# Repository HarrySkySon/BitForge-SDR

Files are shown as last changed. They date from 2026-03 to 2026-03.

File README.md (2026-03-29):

<p align="center">
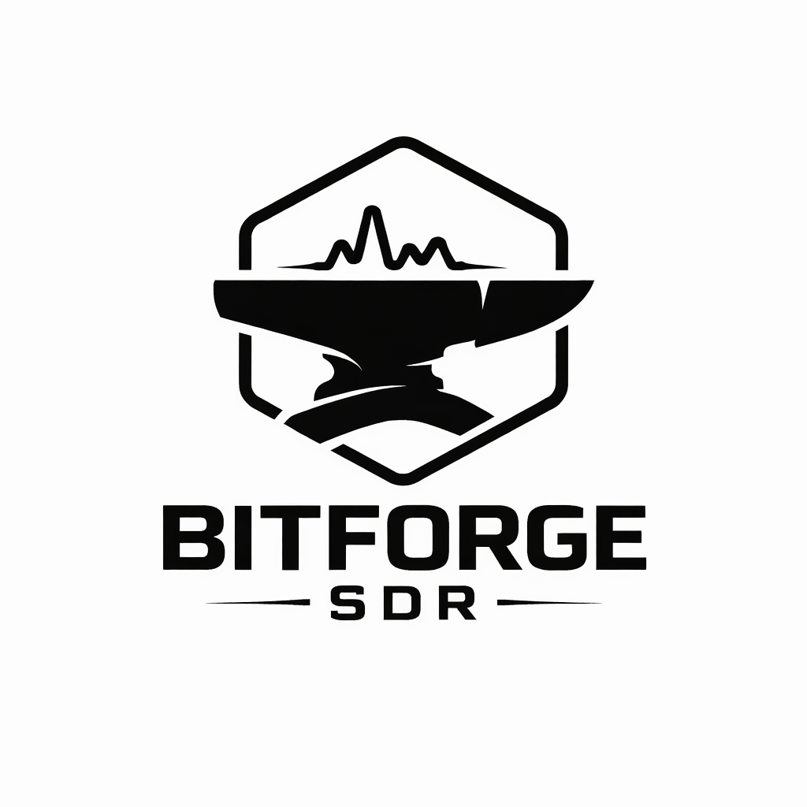
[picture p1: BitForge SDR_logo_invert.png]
BitForge SDR Logo
  
</p>

<h1 align="center">BitForge SDR</h1>

<p align="center">
  <b>Pure Signal. Full Control.</b><br>
  Open-Source 16-bit Direct-Sampling HF SDR Transceiver | 9 kHz -- 72 MHz | >100 dB Dynamic Range
</p>

A high-performance Software Defined Radio transceiver built around the LTC2209 16-bit 153.6 MSPS ADC and MAX5885 16-bit DAC. Designed for demanding HF reception from VLF through the 4-meter band, with full transmit capability and instrumentation-grade dynamic range.

> **Note:** This project is under active development. The hardware design (schematics + PCB) is complete. FPGA firmware is in progress.

---

## Key Specifications

| Parameter | Value |
|---|---|
| **ADC** | LTC2209 -- 16-bit, 153.6 MSPS |
| **DAC** | MAX5885 -- 16-bit, 200 MSPS (clocked at 153.6 MSPS) |
| **Frequency range** | 9 kHz -- 72 MHz (VLF through 4m band) |
| **Nyquist bandwidth** | 76.8 MHz |
| **Dynamic range** | >100 dB (dual DSA cascade) |
| **SFDR** | 100 dB (typical) |
| **Noise figure** | 3.0 dB (LTC6432 dominated) |
| **Output IP3** | +33 dBm (at ADC driver output) |
| **Clock jitter** | <50 fs RMS (Si5391B, integer mode) |
| **Gain range** | -63.5 dB to +15.2 dB (0.25 dB steps) |
| **Filter bands** | 7 switched BPF + wideband master LPF |
| **ADC interface** | LVDS differential (17 pairs, DDR @ 153.6 MHz) |
| **RX/TX switching** | Atomic, single-pin, <100 ns |
| **FPGA platform** | ALINX AXU2CGB (Xilinx Zynq UltraScale+) |

---

## Why This Project?

### 16-bit at 153.6 MSPS -- wider Nyquist than LTC2208 designs

Most open-source direct-sampling SDRs use the LTC2208 (130 MSPS). The LTC2209 pushes the sample rate to 153.6 MSPS, extending the Nyquist bandwidth to 76.8 MHz and comfortably covering the entire 9 kHz -- 72 MHz range without aliasing concerns at the band edges.

### Dual Digital Step Attenuators with 0.25 dB resolution

Two PE43711A DSAs in cascade provide 63.5 dB of digitally controlled attenuation in 0.25 dB steps. This is finer than most SDR designs (which use 0.5 dB or 1 dB steps) and enables precise AGC control from the FPGA without sacrificing signal quality.

### LTC6432 combined LNA/ADC driver -- a unique topology

Instead of the traditional separate-LNA-plus-ADC-driver chain (PGA-103 + ADA4937 or similar), this design uses the LTC6432-15 as a combined low-noise amplifier and differential ADC driver. The result is a simpler signal path with +15.2 dB fixed gain, 3.0 dB noise figure, and +33 dBm OIP3 -- all in a single IC with dual-balun impedance matching.

### 7-band switched filter bank + wideband master LPF

Two PE42582A SP8T switches route the signal through one of seven optimized bandpass filters (90 kHz -- 73 MHz) or a wideband master LPF covering the full 9 kHz -- 72 MHz range. The master LPF provides a panoramic view of the entire HF spectrum for digital waterfall display, while the BPFs deliver sharp selectivity when zoomed into a specific band.

### Si5391B integer-mode clock -- zero fractional spurs

The clock synthesizer operates in pure integer mode: 38.4 MHz TCXO x4 = 153.6 MHz. No fractional dividers means zero fractional spurs on the SDR waterfall -- a real advantage over designs using fractional-N PLLs with 25 MHz references. Clock jitter is below 50 fs RMS, preserving the full 16-bit ADC performance.

### Full transmit path with 16-bit DAC

The MAX5885 16-bit DAC shares the same signal chain (filter bank, LTC6432, and RF switches) in reverse for TX. Atomic RX/TX switching is controlled by a single FPGA pin with <100 ns transition time -- no sequencing logic required.

### Extended range: 9 kHz -- 72 MHz

Coverage extends from VLF (9 kHz) through the entire HF spectrum and up to the 4-meter band (70 MHz). The 3-stage RF choke network in the LNA power supply is specifically designed for continuous performance from 9 kHz to 72 MHz without resonant dips.

---

## Comparison with Existing SDR Platforms

| Parameter | **BitForge SDR** | Hermes-Lite 2 | HPSDR Angelia | RX-888 MKII | Red Pitaya SDRlab 122-16 | Elad FDM-S3 |
|---|---|---|---|---|---|---|
| **ADC resolution** | 16-bit | 12-bit | 16-bit | 16-bit | 16-bit | 16-bit |
| **Sample rate** | 153.6 MSPS | 76.8 MSPS | 122.88 MSPS | 64 MSPS | 122.88 MSPS | 192 MSPS |
| **SFDR** | 100 dB | ~70 dB | 100 dB | 78 dB | 90 dB | 100 dB |
| **Dynamic range** | >100 dB | ~80 dB | >100 dB | ~85 dB | ~90 dB | >100 dB |
| **Frequency range** | 9 kHz -- 72 MHz | 0 -- 38.4 MHz | 0 -- 61.44 MHz | 0 -- 32 MHz | 0 -- 60 MHz | 9 kHz -- 108 MHz |
| **TX capability** | Yes (16-bit DAC) | Yes (12-bit) | Yes | No | Yes (14-bit) | No |
| **Filter bands** | 7 BPF + master LPF | 5 LPF | 7 BPF | None | None | 6 BPF |
| **Clock jitter** | <50 fs | Not specified | Not specified | Not specified | Not specified | Not specified |
| **Gain control step** | 0.25 dB | 1 dB | 0.5 dB | 0.5 dB | Analog | 0.5 dB |
| **ADC driver** | LTC6432 (LNA+driver) | ADC direct | ADA4937 | LTC6401 | ADC direct | Proprietary |
| **License** | CERN-OHL-S v2 | GPL | GPL | Closed | Closed | Closed |
| **Approx. price** | ~$150 (PCB+BOM) | ~$300 | ~$800+ | ~$200 | ~$500 | ~$1,200 |

---

## Architecture

```
                            ┌─────────────────────────────────┐
                            │        FPGA (Zynq US+)          │
                            │   ALINX AXU2CGB via J701/J901  │
                            │                                 │
                            │  J701: ADC LVDS (17 diff pairs) │
                            │  J901: DAC data + control (3.3V)│
                            └──┬──────────────┬───────────────┘
                               │              │
                          ADC LVDS        DAC data + /RX_TX_MODE
                               │              │
┌─────────┐   ┌─────────┐   ┌─┴──────┐   ┌───┴──────┐
│ SMA RX  │   │Block 1  │   │Block 7 │   │ Block 9  │
│  Input  ├──►│DSA1     │   │LTC2209 │   │ MAX5885  │
│  (J101) │   │0-31.75dB│   │ADC     │   │ DAC      │
└─────────┘   └────┬────┘   └───▲────┘   └────┬─────┘
                   │             │              │
              ┌────▼─────────────┴──────────────┴────┐
              │          Block 4: RF Switches         │
              │       3x F2912 (atomic RX/TX)         │
              │  RX: Antenna→ADC  TX: DAC→Antenna     │
              └────────────────┬──────────────────────┘
                               │
                   ┌───────────▼───────────┐
                   │  Block 6: LTC6432     │
                   │  LNA/ADC Driver       │
                   │  +15.2 dB, NF=3.0 dB  │
                   │  Dual balun topology   │
                   └───────────▲───────────┘
                               │
                   ┌───────────┴───────────┐
                   │  Block 5: DSA2        │
                   │  0 -- 31.75 dB        │
                   │  0.25 dB steps        │
                   └───────────▲───────────┘
                               │
              ┌────────────────┴────────────────┐
              │  Blocks 2-3: Switched Filter Bank│
              │  7x BPF + Master LPF (0-72 MHz) │
              │  2x PE42582A SP8T switches       │
              └─────────────────────────────────┘

              ┌─────────────────────────────────┐
              │  Block 8: Clock Generation       │
              │  Si5391B (<50 fs jitter)         │
              │  38.4 MHz TCXO x4 = 153.6 MHz   │
              │  Integer mode, zero spurs        │
              └─────────────────────────────────┘
```

**Signal flow (RX):** Antenna → ESD protection → Balun → DSA1 → Filter Bank → DSA2 → LTC6432 → RF switches → LTC2209 ADC → LVDS → FPGA

**Signal flow (TX):** FPGA → MAX5885 DAC → RF switches → Filter Bank → DSA2 → LTC6432 → RF switches → Antenna

---

## Repository Contents

| Path | Description |
|---|---|
| `README.md` | This file |
| `LICENSE` | CERN Open Hardware Licence v2 -- Strongly Reciprocal |
| `BitForge SDR_logo_invert.png` | Project logo |
| `PROJECT_OVERVIEW_v2.0.md` | Detailed technical overview of all 9 functional blocks |
| `ALINX_Interface_Pinout_Specification.md` | FPGA carrier board connector pinout mapping |
| `FPGA_Interface_Voltage_Analysis.md` | Voltage level and bank compatibility analysis |
| `pcb_design/PCB_STACKUP_IMPEDANCE.md` | PCB stackup and controlled impedance specifications |
| `schematics/All_Bloks_of_project.kicad_sch` | Top-level KiCad schematic (all blocks) |
| `schematics/All_Bloks_of_project.kicad_pcb` | PCB layout |
| `schematics/All_Bloks_of_project.kicad_pro` | KiCad project file |
| `schematics/All_Bloks_of_project.kicad_dru` | Design rules |
| `schematics/production/LTC2209_SDR.zip` | Production Gerber files |
| `schematics/production/LTC2209_SDR_bom.csv` | Bill of Materials |
| `schematics/bom/ibom.html` | Interactive BOM (open in browser) |

---

## Getting Started

### Prerequisites

- **KiCad 8.0** or later -- [https://www.kicad.org/download/](https://www.kicad.org/download/)
- A web browser (for the interactive BOM)

### Viewing the Design

1. **Schematics:** Open `schematics/All_Bloks_of_project.kicad_pro` in KiCad. The top-level schematic contains all 9 functional blocks with hierarchical sheets.

2. **PCB Layout:** Open the same project file and switch to the PCB editor, or open `schematics/All_Bloks_of_project.kicad_pcb` directly.

3. **Interactive BOM:** Open `schematics/bom/ibom.html` in any web browser. This provides a visual, searchable component placement overlay on the PCB -- no KiCad installation required.

4. **Production files:** The `schematics/production/` directory contains ready-to-order Gerber files and BOM.

### FPGA Platform

This board connects to the **ALINX AXU2CGB** carrier board (Xilinx Zynq UltraScale+ XCZU2CG) via two 2x20 pin headers:
- **J701** (mapped to ALINX J12): ADC LVDS interface -- 16 data pairs + 1 clock pair
- **J901** (mapped to ALINX J15): DAC data bus + control signals (3.3V LVCMOS)

See `ALINX_Interface_Pinout_Specification.md` for the complete pin mapping.

---

## License

This project is licensed under the **CERN Open Hardware Licence Version 2 -- Strongly Reciprocal** ([CERN-OHL-S v2](https://ohwr.org/cern_ohl_s_v2.txt)).

See the [LICENSE](LICENSE) file for the full text.

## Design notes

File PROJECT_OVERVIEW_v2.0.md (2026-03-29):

# SDR Receiver/Transceiver Project - Technical Overview

**Version:** 2.9
**Date:** 2026-01-25
**Status:** RX/TX Complete (LVDS interface, 3.3V control, optimized Block 6)

---

## PROJECT SUMMARY

**Name:** Software Defined Radio (SDR) Receiver with LTC2209 ADC
**ADC:** LTC2209 (16-bit, 160 MSPS)
**DAC:** MAX5885 (16-bit, 200 MSPS)
**Frequency Range:** 9 kHz - 72 MHz
**Dynamic Range:** >100 dB (with dual DSA)
**Gain:** 15.2 dB (fixed, LTC6432 LNA/Driver)

---

## BLOCK STRUCTURE

The project consists of **9 functional blocks** with continuous component numbering:

| Block | Prefix | Function | Key ICs | Purpose |
| --- | --- | --- | --- | --- |
| **Block 1** | 100s | Input Stage | PE43711A-Z, TC1-1T | Input protection, balancing, DSA1 |
| **Block 2, 3** | 200s | Switched Filter Bank | 2x PE42582A-X | Multi-band filtering (7 bands) + Master LPF 0 - 72 MHz |
| **Block 4** | 400s | RX/TX RF Switching | 3x F2912NCGI8 | RF switching between RX and TX modes |
| **Block 5** | 500s | Second DSA | PE43711A-Z | Additional digital attenuation |
| **Block 6** | 600s | LNA/ADC Driver | LTC6432AIUF-15 | LNA + differential driver (+15.2dB) for RX/TX |
| **Block 7** | 700s | ADC + Interface | LTC2209, TPS7A9101 | 16-bit ADC + FPGA interface (RX) |
| **Block 8** | 800s | Clock Generation | Si5391B-A-GM | Ultra-low jitter clock (38.4 MHz TCXO -> 153.6 MHz) |
| **Block 9** | 900s | DAC & TX Interface | MAX5885, LP5912 | 16-bit DAC + FPGA interface (TX) |

---

## DETAILED BLOCK DESCRIPTIONS

### **BLOCK 1: Input Stage & DSA1** (100s prefix)

#### **Key Components:**

- **IC101** - LP5907MFX-3.3: Ultra-low noise LDO (3.3V, 250mA)
- **IC104** - PE43711A-Z: 6-bit Digital Step Attenuator (0-31.75 dB, 0.25dB steps)
- **T101** - TC1-1T: 1:1 RF Transformer (50 ohm impedance matching)
- **TVS101** - CDSOD323-T05LC: Transient Voltage Suppressor
- **J101** - SMA RX: Input coaxial connector

#### **Functions:**

1. **ESD/Overvoltage Protection** (TVS101)
2. **Single-ended to Differential Conversion** (T101)
3. **Digital Control Gain** (IC104): 0 to -31.75 dB, FPGA controlled
4. **Clean Power Supply** (IC101) for DSA

#### **Control:**

- **DSA_SCLK, DSA_DATA, DSA_LE1**: SPI control for DSA1 (7-bit attenuation values)

#### **Specifications:**

- **Input impedance:** 50 ohm
- **IP3:** +42 dBm (PE43711A)
- **Insertion Loss:** ~3 dB @ 0 dB attenuation

---

### **BLOCK 2: Switched Filter Bank** (200s prefix)

#### **Key Components:**

- **IC201** - PE42582A-X: SP8T RF Switch (input)
- **IC202** - LP5907MFX-3.3: LDO for switch power supply
- **IC203** - PE42582A-X: SP8T RF Switch (output)
- **L301-L356, C301-C374**: 7x LC Band-Pass Filters
- **Master LPF:** Wideband filter covering the full dynamic range 9 kHz - 72 MHz. Designed to provide a complete passband overview with subsequent digital processing and filtering in the FPGA

#### **Architecture:**

```
IC201 (SP8T) -> [7x Bandpass Filters and Master LPF 9 kHz - 72 MHz] -> IC203 (SP8T)
     |                                        |
  FLT_V1-V4                               FLT_V1-V4
  (4-bit binary)                          (4-bit binary)
```

#### **Filters (7 bands):**

| Band | Filter Path | Frequency Range | Components |
| ---- | --- | --- | --- |
| 1 | RF_FILTR_IN/OUT_1 | 0.09 - 1.6 MHz  | L301-L305, C301-C305 |
| 2 | RF_FILTR_IN/OUT_2 | 1.5 - 4 MHz | L306-L312, C306-C315 |
| 3 | RF_FILTR_IN/OUT_3 | 4 - 8 MHz | L313-L319, C316-C327 |
| 4 | RF_FILTR_IN/OUT_4 | 8 - 15.5 MHz | L320-L327, C328-C341 |
| 5 | RF_FILTR_IN/OUT_5 | 15 - 30 MHz | L328-L333, C342-C351 |
| 6 | RF_FILTR_IN/OUT_6 | 30 - 50 MHz | L334-L337, C352-C358 |
| 7 | RF_FILTR_IN/OUT_7 | 47 - 73 MHz | L338-L347, C359-C374 |
| 8 | MASTER_LPF_IN/OUT | 0.09 - 72 MHz | L338-L347, C359-C374 |

#### **Master LPF:**

- **MASTER_LPF_IN** -> L348-L356 -> **MASTER_LPF_OUT**
- Wideband filter covering the full dynamic range 9 kHz - 72 MHz.

#### **Control:**

- **FLT_V1, FLT_V2, FLT_V3, FLT_V4**: 4-bit binary control for both switches (synchronous switching)
  Band selection is performed programmatically. The user initially sees the full 9 kHz - 72 MHz band. This allows them to view the radio spectrum and choose software tools and filters for signal processing. When the user zooms into a specific range, the corresponding BPF filter is selected, providing fine signal filtering in that band.

#### **Functions:**

####

#### **Specifications:**

- **Isolation:** >55 dB (PE42582A)
- **Insertion Loss:** ~0.5 dB per switch
- **Switching Speed:** <500 ns

---

### **BLOCK 4: RX/TX RF Switching** (400s prefix)

#### **Key Components:**

- **IC401, IC402, IC403** - F2912NCGI8: SP2T RF switches (Renesas)
- **IC404, IC405** - LP5907MFX-3.3: LDO for switch power supply

#### **Functions:**

- **IC401:** TX signal injection from DAC into shared RX/TX signal path (Filter Bank)
- **IC402/IC403:** Routing of LTC6432 differential outputs between ADC (RX) and TX antenna
- **1-pin control:** All switches + ADC/DAC are controlled by a single `/RX_TX_MODE` signal

#### **Architecture:**

```
        RX Mode (/RX_TX_MODE = LOW):
Antenna -> Filter Bank -> LTC6432 -> IC402/IC403 (RF1) -> ADC (active)
                      (DAC shutdown)

        TX Mode (/RX_TX_MODE = HIGH):
DAC (active) -> IC401 (RF2) -> Filter Bank -> LTC6432 -> IC402/IC403 (RF2) -> TX Antenna
                                                    (ADC shutdown)
```

#### **Atomic RX/TX Control (single signal):**

**Switch Control Truth Table:**

| Mode | /RX_TX_MODE | F2912 (IC401-403) | LTC2209 SHDN | MAX5885 PD |
| --- | --- | --- | --- | --- |
| **RX** | LOW (0V) | RF1 ON (RX path)  | LOW (active) | HIGH (off) |
| **TX** | HIGH (3.3V) | RF2 ON (TX path)  | HIGH (off) | LOW (active) |

**Control Signal Path:**

```
FPGA (J15, BANK25/26, 3.3V) -> J901.32 -> RX_TX_MODE
                                          +-- IC401.16 (CTL2) -> F2912 #1
                                          +-- IC402.16 (CTL2) -> F2912 #2
                                          +-- IC403.16 (CTL2) -> F2912 #3
                                          +-- IC701.19 (SHDN) -> LTC2209
```

**Control Current Budget (FPGA 3.3V LVCMOS output):**

| Component | Pins | Current per pin | Total |
| --- | --- | --- | --- |
| F2912 CTL2 (x3) | IC401-403.16  | 500 nA max | **1.5 uA**  |
| LTC2209 SHDN | IC701.19 | ~1 uA | **1 uA** |
| U902 input | Level shifter | ~1 uA | **1 uA** |
| **Total** | | | **~3.5 uA** |

**FPGA IOH/IOL capability: 8-12 mA -> margin >2000x**

#### **F2912 Configuration (3.3V Control Mode):**

- **Pin 18 (LOGICCTL)** = **GND** -> **3.3V logic mode enabled**
- **Pin 19 (ModeCTL)** = VCC -> 1-pin control mode
- **Pin 16 (CTL2)** = RX_TX_MODE -> Control input (3.3V logic)
- **Logic thresholds (3.3V):** VIH min = 2.0V, VIL max = 0.8V

**Advantage of LOGICCTL=GND:**

- Direct control via 3.3V signal from FPGA J15 (BANK25/26)
- Does not require level shifter IC704 (removed)
- Simplified circuit, fewer components

#### **Specifications:**

- **Switching time:** <100 ns (RF switches)
- **Isolation:** >74 dB (RF1/RF2 @ 1 GHz)
- **Insertion Loss:** <0.5 dB @ HF frequencies
- **Control:** Single FPGA pin `/RX_TX_MODE` (LVCMOS33, J901.32)

---

### **BLOCK 5: Second DSA** (500s prefix)

#### **Key Components:**

- **IC501** - LP5907MFX-3.3: LDO for DSA2
- **IC502** - PE43711A-Z: 6-bit Digital Step Attenuator

#### **Functions:**

- **Digital attenuation:** Additional digital attenuation (0 to -31.75 dB). Step size 0.25 dB
- **Dual DSA cascade** with Block 1 for wide dynamic range (0 to -63.5 dB total)

#### **Control:**

- **DSA_SCLK, DSA_DATA, DSA_LE2**: SPI control for DSA2 (7-bit attenuation values)

#### **Specifications:**

- Identical to IC104 (Block 1)
- **Total Gain Range:** 0 to -63 dB (with Block 1)

---

### **BLOCK 6: LNA/ADC Driver** (600s prefix) - **NEW DESIGN**

#### **Key Components:**

- **IC601** - **LTC6432AIUF-15#PBF**: Differential LNA/Driver (+15.2 dB gain)
- **IC602** - TPS7A9401DSCR: Ultra-low noise LDO
- **T601** - TTWB-2-A: 1:2 Input Balun (single-ended to differential), Bandwidth = 50 kHz to 200 MHz
- **T602** - CX2041NLT: 1:1 Output Balun (re-balancing + common-mode biasing), Bandwidth = 50 kHz to 200 MHz
- **L601, L611, L602, L603, L612, L604**: Power supply chokes + output filter inductors
- **C601-C622**: Coupling, bypass, and filter capacitors
- **R601-R608**: Input termination, biasing, output termination

#### **Architecture:**

```
RF_1 -> T601 (1:2 balun) -> IC601 (LTC6432) -> T602 (2:1 balun) -> ADC
       50 ohm single-ended     Diff. Amp         Output balancing   Differential
                           Gain = +15.2dB                           to LTC2209
                                  |
                            IC602 (5V LDO)
```

#### **Pinout LTC6432 (IC601):**

| Pin | Function | Connection |
| --- | --- | --- |
| 5 | NFILT2 | C605 (1uF) filter cap |
| 6 | NFILT1 | C606 (1uF) filter cap |
| 7 | -In | From T601 via C602 |
| 8, 15, 17, 23, 25 | GND | Ground plane |
| 9, 22 | +VS | +5V (from IC602) |
| 12 | -FDBK | C608 (1uF) feedback |
| 13 | -OUT | To T602 via C614 |
| 18 | +OUT | To T602 via C613 |
| 19 | +FDBK | C607 (1uF) feedback |
| 24 | +In | From T601 via C601 |
| 1-4, 10-11, 14-16, 20-21 | DNC | Do Not Connect |

#### **Input Network:**

```
RF_1 (from Block 5) -> T601 (TTWB-2-A, 1:2) -> +/-In (IC601)
                      50 ohm SE -> 200 ohm diff      Pins 24, 7
```

#### **Output Network:**

```
IC601 +/-OUT -> C613/C614 (1uF) --+-- R622/R623 (2.2k ohm shunt)
                               +-- T602 (CX2041NLT, 1:1) -> ADC differential input
                                   Center tap -> LTC2209 VCM
```

#### **Power Supply: 3-Stage RF Choke Network**

Three-stage RF choke network for continuous coverage of the 9 kHz - 72 MHz range:

```
+5V_B6 -+- L601 (470uH) -+- L611 (47uH) -+- L602 (560nH) -+- IC601 +VS
        |                |               |                |
        +- R603 (390 ohm) -+- R620 (82 ohm) -+- R604 (54 ohm) ---+
```

| Stage | Inductor | De-Qing R | Effective Range |
| ----- | --- | --- | --- |
| LF | L601 (470uH) | R603 (390 ohm) | 9 kHz - 1 MHz |
| MF | L611 (47uH)  | R620 (82 ohm)  | 500 kHz - 6 MHz |
| HF | L602 (560nH) | R604 (54 ohm)  | 5 MHz - 72 MHz  |

**Specifications:**

- Total DCR: 1.86 ohm -> DC drop: 130 mV -> VCC = 4.87V (within specification)
- Z_choke @ 72 MHz: 516 ohm
- Worst resonance: Q=72 @ 213 kHz (well damped)

#### **LTC6432 Specifications:**

- **Gain:** +15.2 dB (fixed)
- **Noise Figure:** 3.0 dB @ 100 MHz
- **Output IP3:** +33 dBm
- **Bandwidth:** 100 kHz to 1400 MHz (-3dB)
- **Output Impedance:** 50 ohm differential
- **Supply Current:** 165 mA @ 5V
- **DC Power:** 850mW

#### **Block Functions:**

1. **Low Noise Amplification:** +15.2 dB with NF = 3.0 dB
2. **Single-ended to Differential Conversion** (T601)
3. **Differential Output Balancing** (T602)
4. **ADC Common-Mode Biasing** (T602 center tap -> VCM)
5. **Output Filtering** (L605/L606 + C617/C618/C619)
6. **Clean Power Supply** (IC602 ultra-low noise LDO)

#### **Key Features:**

- **Dual Balun Architecture:** T601 (TTWB-2-A, 1:2) + T602 (CX2041NLT, 1:1), BW = 50 kHz - 200 MHz
- **3-Stage RF Choke:** Continuous coverage 9 kHz - 72 MHz without resonant dips
- **Optimized De-Qing:** R603=390 ohm, R620=82 ohm, R604=54 ohm for Q-factor control
- **Shunt Resistors:** R622/R623 (2.2k ohm) for additional LC resonance damping
- **T602 VCM Biasing:** Center tap connected to LTC2209 VCM for ADC DC biasing

---

### **BLOCK 7: ADC & FPGA Interface** (700s prefix)

#### **Key Components:**

- **IC701** - LTC2209IUPPBF: 16-bit ADC (153.6 MSPS)
- **IC702** - TPS7A9101DSKT: Precision LDO for analog supply (3.3V)
- **IC703** - LP5907MFX-1.8: LDO for digital outputs (1.8V)
- **J701** - Pin Header 2x20: FPGA interface connector (LVDS data)
- **J901** - Pin Header 2x20: Control signals + ADC_OF (3.3V)
- **C701** - 10uF: VCM bypass capacitor
- **C702, C711, C712** - Decoupling capacitors for VDD (3.3V)
- **C703, C718** - Decoupling capacitors for OVDD (1.8V)

#### **ADC Specifications:**

- **Resolution:** 16 bits
- **Sample Rate:** 153.6 MSPS (from Block 8)
- **Nyquist Bandwidth:** 76.8 MHz (covers 9 kHz - 72 MHz range)
- **Noise Floor:** 77.3 dBFS
- **SFDR:** 100 dB (typical)
- **Output Format:** 2's Complement (16-bit parallel)
- **Output Mode:** **LVDS Differential** (17 pairs via J701)
- **Power Dissipation:** ~1.0W @ 153.6 MSPS

#### **Output Mode: LVDS Differential**

**Why LVDS:**

- **High speed:** DDR at 153.6 MHz = 307.2 Mbps per lane
- **Noise immunity:** Differential signals with common-mode rejection
- **Compatibility:** FPGA HP banks (BANK65/66) have native LVDS support
- **Termination:** Built-in 100 ohm resistors in FPGA (DIFF_TERM_ADV TERM_100)

**LTC2209 LVDS Output Structure:**

- **DA0-DA15:** 8 differential pairs (Bus A)
- **DB0-DB15:** 8 differential pairs (Bus B)
- **CLKOUTA/CLKOUTB:** 1 differential pair (Data Clock Output)
- **OFA/OF-:** Overflow -> J901 pins 21/22 (single-ended 3.3V)
- **Total LVDS pairs on J701:** 17 (all J12 pairs utilized)

**LVDS Electrical Characteristics:**

| Parameter | Value |
| --- | --- |
| Common Mode (VOS) | 1.125V - 1.2V - 1.375V |
| Differential (VOD) | 247mV - 350mV - 454mV |
| FPGA Input Common Mode | 0.3V - 1.5V (compatible) |
| FPGA Min Differential  | >100mV (350mV >> 100mV OK) |
| Termination | 100 ohm internal in FPGA |

#### **Control Pins Configuration:**

| Pin | Name  | Connected  | Function | Reasoning |
| --- | ----- | --- | --- | --- |
| 1 | SENSE | VDD (3.3V) | Internal 2.5V reference | Uses internal bandgap reference |
| 19  | SHDN  | RX_TX_MODE | Shutdown control | 3.3V from FPGA via J901.32 |
| 20  | DITH  | GND | Dither disabled | Better SNR for SDR (~3dB improvement) |
| 61  | LVDS  | VDD (3.3V) | LVDS mode enabled | Differential output via J701 |
| 62  | MODE  | VDD (3.3V) | 2's Complement format | Standard for DSP/SDR processing |
| 63  | RAND  | GND | Normal output | No XOR randomization needed |
| 64  | PGA | GND | Gain=1, 2.25Vpp range | LTC6432 provides sufficient gain |

#### **Dual Supply Architecture:**

- **VDD (3.3V):** Analog core supply (pins 5,6,15,16,17)
  - Source: IC702 (TPS7A9101) ultra-low noise LDO
  - Decoupling: C702 (1uF), C711 (47uF), C712 (10nF)

- **OVDD (1.8V):** Digital output drivers (pins 32,49)
  - Source: IC703 (LP5907-1.8) ultra-low noise LDO
  - Decoupling: C703 (1uF), C718 (2.2uF)
  - Powers LVDS output drivers

- **VCM (Pin 3):** Output voltage reference (0.95V typical)
  - Bypass: C701 (10uF, >=2.2uF per datasheet)
  - Connected to T602 center tap for DC bias

#### **Analog Inputs:**

- **IN+ (Pin 8), IN- (Pin 9):** Differential analog inputs
  - Connected to ADC_P_OUT, ADC_N_OUT (from Block 6 via T602)
  - Input range: 2.25Vp-p differential (PGA=0)
  - Series termination: R607/R608 (25 ohm each)

#### **Clock Input:**

- **ENC+ (Pin 12), ENC- (Pin 13):** Differential clock inputs
  - Connected to CLK_0, CLK_B (from Block 8)
  - Clock frequency: 153.6 MHz (from Si5391B OUT0/OUT0b)
  - AC coupled via C809, C818 (100nF)
  - Terminated: R701 (100 ohm differential)

#### **Digital Outputs (LVDS to FPGA via J701):**

- **DA0-DA15, DB0-DB15:** 16 differential pairs (32 lines)
  - Output standard: LVDS (VOS=1.2V, VOD=350mV)
  - Data format: 2's Complement (MODE pin = VDD)
  - DDR transfer: both edges of CLKOUT
  - Connected to J701 pins 3-36 -> FPGA J12 (BANK65/66)

- **CLKOUTA/CLKOUTB (Pins 41, 40):** Data clock output
  - LVDS differential pair
  - Connected to J701 pins 15/16 -> FPGA IO1_7 (GC-capable)
  - Frequency: 153.6 MHz (same as ENC clock)

- **OFA/OF- (Pins 60, 59):** Overflow indicator
  - Connected to J901 pins 21/22 -> FPGA BANK25/26 (3.3V)
  - Used as single-ended signals on HR banks

---

### **BLOCK 8: Clock Generation** (800s prefix)

#### **Key Components:**

- **IC801** - Si5391B-A-GM: Ultra-low jitter clock generator (QFN-65, 12 outputs)
- **X801** - 38.4 MHz TCXO: Temperature-compensated crystal oscillator
- **C801-C817** - Decoupling capacitors: Power supply filtering
- **R801, R802** - 2.2k ohm: I2C pull-up resistors

#### **Architecture:**

```
X801 (38.4 MHz TCXO) -> IC801 (Si5391B PLL) -> OUT0/OUT0b (153.6 MHz) -> LTC2209 CLK+/-
                         ^
                    I2C_SCL, I2C_SDA
                    (FPGA configuration)
```

#### **Clock Generation:**

```
38.4 MHz TCXO (X801)
    | XA/XB (pins 8/9)
Si5391B DSPLL (IC801)
    +- VCO: ~5 GHz (internal)
    +- Integer Mode (clean spectrum, no fractional spurs)
    +- MultiSynth dividers
         |
OUT0/OUT0b (pins 24/23) -> 153.6 MHz differential -> LTC2209 CLK+/- (IC701.12/13)
```

#### **I2C Interface:**

- **I2C_SEL (pin 39)** = +1.8V -> I2C mode
- **SCLK (pin 16)** -> FPGA I2C_SCL (with 2.2k ohm pull-up)
- **SDA (pin 18)** -> FPGA I2C_SDA (with 2.2k ohm pull-up)
- **A1/A0 (pins 17/19)** = GND -> I2C address **0x68**

#### **Input Selection:**

- **IN_SEL0/IN_SEL1 (pins 3/4)** = GND -> explicit XA/XB selection (crystal input)
- **XA/XB (pins 8/9)** -> connected to 38.4 MHz TCXO (X801)

#### **Si5391B Specifications for Project Requirements:**

- **Jitter:** <50 fs RMS (Integer Mode, Precision Calibration)
- **Output frequency:** 153.6 MHz (4/1 ratio - Integer Mode) (programmable via I2C)
- **Sample rate:** 153.6 MSPS
- **Nyquist bandwidth:** 76.8 MHz
- **Coverage:** 9 kHz - 72 MHz with margin
- **Reference:** 38.4 MHz TCXO
- **Mode:** Integer (38.4 MHz x 4/1 = 153.6 MHz) -> no fractional spurs
- **Usable bandwidth:** 0-68 MHz (with margin up to 72 MHz)
- **Filter transition band:** 68-76.8 MHz (~12% margin)
- **Data throughput:** 153.6 MSPS x 16 bit = 2.46 Gbit/s
- **Output format:** Differential LVDS/LVPECL (configurable)
- **Power:** 1.8V (VDD core) + 3.3V (VDDA analog)

#### **Clock Performance:**

**Jitter budget (for LTC2209 16-bit ADC):**

```
ADC SNR = -20 x log10(2*pi * f_sample * t_jitter)

@ 153.6 MSPS, 153.6 MHz clock:
  Si5391B: <50 fs RMS
  -> Jitter-limited SNR: ~94 dBFS
  -> ENOB: ~15.3 bits (theoretical)
  -> LTC2209 spec: 77.3 dBFS noise floor (16-bit ENOB achievable!)
```

#### **Integer Mode Advantage:**

**Fractional-N vs Integer Mode:**

- **Fractional:** 25 MHz x 6.144 = 153.6 MHz -> produces spectral spurs (birdies on SDR waterfall)
- **Integer:** 38.4 MHz x 4 = 153.6 MHz -> clean spectrum, ideal for SDR

**Integer Mode calculation:**

```
38.4 MHz x 4 = 153.6 MHz
-> Simple integer multiplier (4x)
-> No fractional dividers needed
-> Zero fractional spurs
```

#### **Block Functions:**

1. **Ultra-low jitter clock generation** (<50 fs RMS)
2. **Integer Mode operation** (clean spectrum without fractional spurs)
3. **Dual LDO power supply** (analog/digital power isolation)
4. **I2C programmability** (ClockBuilder Pro configuration)
5. **Input filtering** (ferrite beads + decoupling caps)
6. **Temperature-stable reference** (38.4 MHz TCXO)

#### **Control:**

- **I2C_SCL, I2C_SDA:** Si5391B programming (address 0x68)
- **Configuration:** Via ClockBuilder Pro software (Silicon Labs)
- **Startup:** Configuration loaded via I2C after power-on
  I2C_SCL / I2C_SDA are REQUIRED in the current design because:
  1. Standard Si5391B-A-GM is used - no custom NVM
  2. At each power-up the FPGA must load the configuration:
  - Input: 38.4 MHz TCXO on XA/XB
  - Output: 153.6 MHz LVDS on OUT0/OUT0b
  - Mode: Integer (no fractional spurs)
  - PLL settings: 38.4 x 4 = 153.6 MHz
  3. Without I2C programming, the Si5391B will operate with factory default settings
  Alternative (for future revisions):
  Order a factory pre-programmed Si5391B through ClockBuilder Pro:
  - Silicon Labs will assign a unique part number (Si5391B-Axxxxx-GM)
  - The IC will automatically start with the correct configuration
  - I2C can then be removed or kept only for monitoring

#### **FPGA Interface:**

**Connection via I2C:**

```
FPGA (J12) -> J701 -> Si5391B
  Pin 34 (IO1_16P, C8) -> I2C_SCL -> IC801.16 (with 2.2k ohm pull-up)
  Pin 35 (IO1_17N, A8) -> I2C_SDA -> IC801.18 (with 2.2k ohm pull-up)
```

**Configuration:**

- **I2C Address:** 0x68 (7-bit, A1=GND, A0=GND)
- **Clock speed:** 400 kHz (Fast Mode)
- **Config size:** ~300 bytes (ClockBuilder Pro generated)
- **Init time:** ~25-40 ms (once at boot)

**Initialization Sequence:**

1. Power-on -> POR (~10 ms)
2. FPGA I2C write (~5-10 ms) -> config registers
3. PLL lock (~10-20 ms)
4. Clock ready (153.6 MHz)

#### **Power Architecture (CRITICAL FEATURE!):**

**Always-on power supply (independent of RX/TX mode):**

```
+3.3V (always on) -> Si5391B
```

**Why always on:**

- TX path (MAX5885 DAC) also requires a clock
- RX and TX share a single clock source
- Configuration loaded once at boot (no re-init required after mode switching)
- PLL always locked -> stable clock

**Power Consumption:**

- **Si5391B:** ~165 mA @ 1.8V/3.3V -> **~357 mW** (always on)
- **For comparison:** LTC6432 = 850 mW, TX PA = 5-10W
- **Conclusion:** Negligible power consumption, but critical advantage in switching speed!

---

### **BLOCK 9: DAC & TX Interface** (900s prefix)

#### **Key Components:**

- **IC901** - MAX5885EGM+D: 16-bit DAC (153.6 MSPS, TX path)
- **U901** - TPS7A9401DSCR: Ultra-low noise LDO (3.3V, 0.46 uVRMS)
- **U902** - SN74LV1T04DCKR: Inverter for PD control
- **T902** - RF Transformer (center-tapped balun)
- **R903, R904** - 25 ohm: DC return path resistors
- **R901** - 2k ohm: Full-scale current set resistor
- **C915/C916, C917/C918** - Parallel decoupling (1uF || 100nF)

#### **DAC Specifications:**

- **Resolution:** 16 bits, 200 MSPS
- **Update Rate:** 153.6 MSPS (from Block 8, OUT3/OUT3b)
- **Nyquist Bandwidth:** 76.8 MHz (covers 9 kHz - 72 MHz)
- **Output Mode:** Differential current outputs (IOUTP, IOUTN)
- **Full-Scale Current:** 19.2 mA (with R901 = 2k ohm)
- **Output Format:** 2's Complement (16-bit parallel)

#### **Output Stage:**

```
IC901 Pin 19 (IOUTP) --+-- R904 (25 ohm) -> GND  (DC path)
                       +-- C917 (1uF)  |
                       +-- C918 (100nF)-+--> T902 Pin 3

IC901 Pin 18 (IOUTN) --+-- R903 (25 ohm) -> GND  (DC path)
                       +-- C915 (1uF)  |
                       +-- C916 (100nF)-+--> T902 Pin 1

T902 Center Tap --> C919 (100nF) --> GND
T902 Output --> RF Switches (shared RX/TX signal path)
```

**Parallel Decoupling:** 1uF || 100nF provides low impedance across the full 9 kHz - 72 MHz range

#### **TX Architecture:**

The TX signal uses the **shared signal path** with RX through:

- Block 2-3: Filter Bank (PE42582A switches)
- Block 5: DSA (bypass in TX mode)
- Block 6: LTC6432 amplifier
- RF switches control signal direction (RX/TX)

---

## SIGNAL FLOW

```
+-------------+
|   SMA RX    | RF Input (1-30 MHz)
|   (J101)    |
+------+------+
       | 50 ohm single-ended
+------v--------------------------------------------------------+
| BLOCK 1: Input Stage                                          |
|  TVS101 -> T101 (1:1) -> IC104 (DSA1: 0 to -31.75dB)        |
|                              ^ DSA_SCLK, DSA_DATA, DSA_LE1   |
|                              ^ +5V (always on)                |
+------+--------------------------------------------------------+
       | Differential
+------v--------------------------------------------------------+
| BLOCK 2: Switched Filter Bank                                 |
|  IC201 (SP8T) -> [7x BPF] -> IC203 (SP8T) -> Master LPF     |
|       ^ FLT_V1-V4            ^ FLT_V1-V4                     |
|       ^ +5V (always on)                                       |
+------+--------------------------------------------------------+
       | Filtered differential
+------v--------------------------------------------------------+
| BLOCK 5: Second DSA                                           |
|  IC502 (DSA2: 0 to -31.75dB)                                 |
|         ^ DSA_SCLK, DSA_DATA, DSA_LE2                        |
|         ^ +5V (always on)                                     |
+------+--------------------------------------------------------+
       | Attenuated differential
       | RF_1 (single-ended equivalent)
+------v--------------------------------------------------------+
| BLOCK 6: LNA/ADC Driver                                      |
|  T601 (1:2) -> IC601 (LTC6432, +15.2dB) -> T602 (1:1)       |
|               |                              |                |
|               IC602 (5V LDO)                VCM -> ADC        |
|               ^ +5V (always on)                               |
+------+----------------------------------------+---------------+
       | ADC_P_OUT, ADC_N_OUT (differential)     | ADC_VCM
       | 2Vp-p @ 200 ohm impedance               |
+------v-----------------------------------------v--------------+
| BLOCK 7: ADC & Interface                                      |
|  IC701 (LTC2209: 16-bit, 153.6 MSPS)                         |
|    +- ADC_CLK_IN <- Block 8 (153.6 MHz)                      |
|    +- ADC_D[15:0] + DCO -> FPGA (J701)                       |
|  IC702, IC703: Power supplies                                 |
|    ^ +5V (always on)                                          |
+------+-------------------+------------------------------------+
       |                   | ADC_CLK_IN
       |         +---------v------------------------------------------+
       |         | BLOCK 8: Clock Generation                          |
       |         |  X801 (38.4 MHz TCXO)                              |
       |         |    |                                               |
       |         |  IC801 (Si5391B: <50fs jitter)                     |
       |         |    | Integer Mode (no spurs)                       |
       |         |  OUT0/OUT0b -> 153.6 MHz diff.                     |
       |         |  U801/U802: Dual LDO (1.8V + 3.3V)                |
       |         |    ^ +5V (always on)                               |
       |         |    ^ I2C_SCL, I2C_SDA (FPGA config)                |
       |         +----------------------------------------------------+
       |
   +---v---------+                 +----------------------------------+
   |   FPGA      | <-/RX_TX_MODE--| BLOCK 4: RX/TX RF Switching      |
   |   (J701)    |   (atomic)     |  3x F2912NCGI8 (SP2T switches)   |
   +-------------+                |  + ADC SHDN + DAC PD control      |
                                  |  Current: ~3.5uA from FPGA pin    |
                                  +----------------------------------+
```

---

## POWER DISTRIBUTION

### **Supply Rails:**

| Rail | Voltage | Source | Load | Current |
| --- | --- | --- | --- | --- |
| **+5V** | 5.0V | External | All blocks (always on) | ~1.2A |
| **+5V_OUT2** | 5.0V | IC602 (Block 6) | IC601 (LTC6432) | 50mA |
| **+3.3V_CLK** | 3.3V | U802 (Block 8) | IC801 VDDA (analog PLL) | ~80mA |
| **+1.8V_CLK** | 1.8V | U801 (Block 8) | IC801 VDD + VDDO (digital)  | ~85mA |
| **+3.3V_DIGITAL** | 3.3V | IC702 (Block 7) | IC701 digital I/O | ~50mA |
| **+3.3V_ANALOG**  | 3.3V | LDOs (Blocks 1,2,4,5) | DSA + RF Switches | ~180mA  |
| **+1.8V_ADC** | 1.8V | IC703 (Block 7) | IC701 digital core | ~40mA |

### **Power Management:**

- **All blocks are always on** - no power switching

**ADC/DAC Control (single /RX_TX_MODE signal from FPGA):**

- **RX_TX_MODE** (3.3V LVCMOS via J901.32):
  - Direct connection to IC701.19 (LTC2209 SHDN)
  - Direct connection to F2912 switches (IC401-403.CTL2)
  - RX Mode: LOW -> SHDN=LOW (ADC active)
  - TX Mode: HIGH -> SHDN=HIGH (ADC shutdown)

- **U902** (SN74LV1T04): Inverter for DAC PD control
  - Input: /RX_TX_MODE (J901.32)
  - Output: IC901.10 (MAX5885 PD, inverted)
  - RX Mode: LOW -> PD=HIGH (DAC powered down)
  - TX Mode: HIGH -> PD=LOW (DAC active)

### **Power Architecture:**

- **All blocks are always on** - simplified architecture without power switching
- **Advantage:** Instant RX/TX switching via RF switches (<100 ns)
- **ADC/DAC control:** Shutdown via SHDN/PD pins instead of power supply switching
- **Power consumption:** ~1.2A @ 5V constant (TX and RX modes are identical)

---

## FPGA CONTROL INTERFACE

### **Control Signal Architecture:**

**DSA Control (SPI):**

- **Shared SPI bus** for DSA1 and DSA2 (IC104, IC502)
- **DSA_SCLK, DSA_DATA:** shared bus (clock + data)
- **DSA_LE1, DSA_LE2:** separate Latch Enable (chip select) for each DSA
- **Pins required:** 4 (saving 2 pins compared to separate SPI buses)

**Filter Control (Binary):**

- **4-bit binary control** for PE42582A-X switches (IC201, IC203)
- **FLT_V1-V4:** parallel control of both switches (synchronous switching)
- **Channels:** 16 possible (8 used: 7 BPF + Master LPF)

**System Control (atomic single-signal control):**

- **/RX_TX_MODE:** single control signal for RX/TX switching (J901.32, LVCMOS33)
  - LOW (0V) = RX mode (ADC active, DAC shutdown, RF1 path)
  - HIGH (3.3V) = TX mode (DAC active, ADC shutdown, RF2 path)
  - Controls: F2912 switches (IC401-403.CTL2) + LTC2209 SHDN (direct) + MAX5885 PD (U902)
  - Load current: ~3.5 uA (margin >2000x from FPGA IOH/IOL)

### **J701 Connector Pinout (LTC2209 LVDS Interface):**

J701 is now used **exclusively for the LVDS interface** with the LTC2209 ADC.

| Pin | Signal | Direction  | Description |
| ----- | --- | --- | --- |
| 1 | GND | -- | Ground |
| 2 | +5V | Power | Main power supply |
| 3-4 | DB0/DB1 | ADC -> FPGA | LVDS Data Bus B pair 0 |
| 5-6 | DB2/DB3 | ADC -> FPGA | LVDS Data Bus B pair 1 |
| 7-8 | DB4/DB5 | ADC -> FPGA | LVDS Data Bus B pair 2 |
| 9-10  | DB6/DB7 | ADC -> FPGA | LVDS Data Bus B pair 3 |
| 11-12 | DB8/DB9 | ADC -> FPGA | LVDS Data Bus B pair 4 |
| 13-14 | DB10/DB11 | ADC -> FPGA | LVDS Data Bus B pair 5 |
| 15-16 | CLKOUT+/- | ADC -> FPGA | **DCO (GC-capable IO1_7)** |
| 17-18 | DB12/DB13 | ADC -> FPGA | LVDS Data Bus B pair 6 |
| 19-20 | DB14/DB15 | ADC -> FPGA | LVDS Data Bus B pair 7 |
| 21-22 | DA0/DA1 | ADC -> FPGA | LVDS Data Bus A pair 0 |
| 23-24 | DA2/DA3 | ADC -> FPGA | LVDS Data Bus A pair 1 |
| 25-26 | DA4/DA5 | ADC -> FPGA | LVDS Data Bus A pair 2 |
| 27-28 | DA6/DA7 | ADC -> FPGA | LVDS Data Bus A pair 3 |
| 29-30 | DA8/DA9 | ADC -> FPGA | LVDS Data Bus A pair 4 |
| 31-32 | DA10/DA11 | ADC -> FPGA | LVDS Data Bus A pair 5 |
| 33-34 | DA12/DA13 | ADC -> FPGA | LVDS Data Bus A pair 6 |
| 35-36 | DA14/DA15 | ADC -> FPGA | LVDS Data Bus A pair 7 |
| 37-38 | GND | -- | Ground |
| 39-40 | +3.3V | Power | 3.3V supply |

**Note:** All 17 differential pairs on J701/J12 are used for LVDS. DCO is assigned to GC-capable pair IO1_7 (pins 15-16).

### **J901 Connector Pinout (DAC Data + Control Signals, 3.3V):**

J901 connects to ALINX J15 -> FPGA BANK25/26 (HR banks, VCCO = 3.3V LVCMOS).
Used for **DAC TX data, control signals, and ADC overflow**.

| Pin | Signal | J15 FPGA Pin | Direction | Description |
| --- | --- | --- | --- | --- |
| 1 | GND | -- | -- | Ground |
| 2 | +5V | VCC5V | Power | 5V supply from ALINX |
| 3 | -- | IO2_1N (A11) | -- | Not connected |
| 4 | TX_SEL0 | IO2_1P (A12) | FPGA -> DAC | MAX5885 mode select (IC901.30) |
| 5 | TX_D15 | IO2_2N (A13) | FPGA -> DAC | DAC data bit 15 (IC901.33) |
| 6 | TX_D14 | IO2_2P (B13) | FPGA -> DAC | DAC data bit 14 (IC901.34) |
| 7 | TX_D13 | IO2_3N (A14) | FPGA -> DAC | DAC data bit 13 (IC901.35) |
| 8 | TX_D12 | IO2_3P (B14) | FPGA -> DAC | DAC data bit 12 (IC901.36) |
| 9 | TX_D11 | IO2_4N (E13) | FPGA -> DAC | DAC data bit 11 (IC901.37) |
| 10  | TX_D10 | IO2_4P (E14) | FPGA -> DAC | DAC data bit 10 (IC901.38) |
| 11  | TX_D9 | IO2_5N (A15) | FPGA -> DAC | DAC data bit 9 (IC901.39) |
| 12  | TX_D8 | IO2_5P (B15) | FPGA -> DAC | DAC data bit 8 (IC901.40) |
| 13  | TX_D7 | IO2_6N (C13) | FPGA -> DAC | DAC data bit 7 (IC901.41) |
| 14  | TX_D6 | IO2_6P (C14) | FPGA -> DAC | DAC data bit 6 (IC901.44) |
| 15  | TX_D5 | IO2_7N (B10) | FPGA -> DAC | DAC data bit 5 (IC901.45) |
| 16  | TX_D4 | IO2_7P (C11) | FPGA -> DAC | DAC data bit 4 (IC901.46) |
| 17  | TX_D3 | IO2_8N (D14) | FPGA -> DAC | DAC data bit 3 (IC901.47) |
| 18  | TX_D2 | IO2_8P (D15) | FPGA -> DAC | DAC data bit 2 (IC901.48) |
| 19  | TX_D1 | IO2_9N (F11) | FPGA -> DAC | DAC data bit 1 (IC901.1) |
| 20  | TX_D0 | IO2_9P (F12) | FPGA -> DAC | DAC data bit 0 (IC901.2) |
| 21  | TX_XOR | IO2_10N (H13)| FPGA -> DAC | MAX5885 XOR input (IC901.3) |
| 22  | -- | IO2_10P (H14)| -- | Not connected |
| 23  | ADC_OF_N | IO2_11N (G14)| ADC -> FPGA | LTC2209 Overflow- (IC701.59), 47 ohm series |
| 24  | ADC_OF_P | IO2_11P (G15)| ADC -> FPGA | LTC2209 Overflow+ (IC701.60), 47 ohm series |
| 25  | DSA_LE2 | IO2_12N (F10)| FPGA -> DSA2 | PE43711 #2 Latch Enable (via R912, 47 ohm) |
| 26  | DSA_LE1 | IO2_12P (G11)| FPGA -> DSA1 | PE43711 #1 Latch Enable (via R913, 47 ohm) |
| 27  | DSA_SCLK | IO2_13N (H12)| FPGA -> DSA | DSA SPI Clock (via R910, 47 ohm) |
| 28  | DSA_DATA | IO2_13P (J12)| FPGA -> DSA | DSA SPI Data (via R911, 47 ohm) |
| 29  | FLT_V2 | IO2_14N (J14)| FPGA -> Filters| Filter select bit 1 (via R918, 47 ohm) |
| 30  | FLT_V1 | IO2_14P (K14)| FPGA -> Filters| Filter select bit 0 (via R914, 47 ohm) |
| 31  | FLT_V4 | IO2_15N (K12)| FPGA -> Filters| Filter select bit 3 (via R917, 47 ohm) |
| 32  | FLT_V3 | IO2_15P (K13)| FPGA -> Filters| Filter select bit 2 (via R915, 47 ohm) |
| 33  | I2C_SDA | IO2_16N (L13)| FPGA <-> Si5391B| I2C Data (4.7k ohm pull-up, no series R) |
| 34  | RX_TX_MODE | IO2_16P (L14)| FPGA -> System | **Atomic RX/TX** (F2912+LTC2209+DAC, via R916 47 ohm)|
| 35  | -- | IO2_17N (G10)| -- | Not connected |
| 36  | I2C_SCL | IO2_17P (H11)| FPGA -> Si5391B| I2C Clock (4.7k ohm pull-up, no series R) |
| 37  | GND | -- | -- | Ground |
| 38  | GND | -- | -- | Ground |
| 39  | +3.3V | VCC_3V3 | Power | 3.3V supply from ALINX |
| 40  | +3.3V | VCC_3V3 | Power | 3.3V supply from ALINX |

**Note:** All signals through J901/J15 use 3.3V LVCMOS (FPGA BANK25/26, HR banks).
DAC clock (DAC_CLK_P/N) is routed directly from Si5391B (IC801.34/35) to MAX5885 (IC901.6/7) -- NOT through J901.

**WARNING:** Maximum LVCMOS33 output speed on HR banks is ~100-125 MHz (DS925).
The DAC operates at 153.6 MSPS -- this exceeds the specification. See the compatibility analysis section below.

---

## SYSTEM PERFORMANCE TARGETS

### **RF Performance:**

- **Frequency Range:** 9 kHz - 72 MHz
- **Input Impedance:** 50 ohm (VSWR < 1.5:1)
- **Gain Range:** -63.5 dB to +15.2 dB (total)
  - DSA1: 0 to -31.75 dB (Block 1)
  - DSA2: 0 to -31.75 dB (Block 5)
  - LNA: +15.2 dB (Block 6, fixed)
- **Noise Figure:** ~3.0 dB @ 0dB attenuation (dominated by LTC6432)
- **IP3:** >+25 dBm (at ADC input)
- **Dynamic Range:** >100 dB (with dual DSA)

### **Filter Bank:**

- **Bands:** 7 switchable bandpass filters + Master LPF
- **Isolation:** >55 dB between bands
- **Insertion Loss**: <3 dB per band

---

## KEY DESIGN FEATURES

### **1. Dual DSA Architecture**

- **Wide dynamic range control:** 0 to -63.5 dB in 0.25 dB steps
- **Prevents ADC overload** for strong signals
- **Maintains low noise floor** for weak signals

### **2. LTC6432 LNA/Driver Integration**

- **Combines LNA + ADC driver** in a single IC
- **Fixed gain** +15.2 dB (no adjustment needed)
- **Low noise figure 3.0 dB** for sensitivity
- **High IP3 +33 dBm** for linearity
- **Dual balun architecture** for optimal impedance matching
- **Differential outputs** native for LTC2209

### **3. Switched Filter Bank**

- **7 programmable bands** for selectivity
- **Dual SP8T switches** (input + output) for isolation
- **Master LPF** wideband 9 kHz - 72 MHz range for digital analysis and signal processing

---

### 4. Power Distribution

- **Separate LDOs** for each block
- **Ultra-low noise TPS7A9401DSCR** for LTC6432
- **Dual LC filtering** in LNA power rails
- **Ferrite beads + bypass capacitors** on all rails

### **5. Differential Signal Path**

- **Balanced transmission** from Block 1 to ADC
- **Common-mode noise rejection**
- **Optimal ADC driving** with T602 balun

---

## DOCUMENTATION FILES

| File | Description | Status |
| --- | --- | --- |
| **PROJECT_OVERVIEW_v2.0.md** | This file - general project overview | Complete |
| **Block1_Input_DSA_Documentation.md** | Detailed Block 1 documentation | To be created |
| **Block2_Filter_Bank_Documentation.md** | Detailed Block 2 documentation | To be created |
| **Block4_Power_Control_Documentation.md**  | Detailed Block 4 documentation | To be created |
| **Block5_DSA2_Documentation.md** | Detailed Block 5 documentation | To be created |
| **Block6_LTC6432_Driver_Documentation.md** | Detailed Block 6 documentation | To be created |
| **Block7_LTC2209_ADC_Documentation.md** | Detailed Block 7 documentation | To be created |

---

## VERSION HISTORY

| Version | Date | Changes |
| --- | --- | --- |
| **1.0** | 2026-01-07 | Initial design with ADA4937 driver + PGA103+ LNA |
| **2.0** | **2026-01-09** | **Major redesign: removed Block 4, replaced Block 6 with LTC6432** |
| **2.1** | **2026-01-10** | **Added new Block 4 (RX/TX Power Control with TPS22976)** |
| **2.2** | **2026-01-11** | **Block 4: Software inversion in FPGA instead of IC402** |
| **2.3** | **2026-01-11** | **Added Block 8 (Clock Generation with Si5391B)** |
| **2.4** | **2026-01-13** | **Block 7: Updated ADC documentation (153.6 MSPS, CMOS mode)** |
| **2.5** | **2026-01-13** | **Added TX path: Block 9 (MAX5885 DAC) + Block 10 (LTC6432 TX driver)** |
| **2.6** | **2026-01-14** | **New TX architecture: removed Block 10, shared RX/TX path through Block 6** |
| **2.7** | **2026-01-18** | **Atomic RX/TX control: single /RX_TX_MODE signal controls switches + ADC/DAC** |
| **2.8** | **2026-01-25** | **LVDS interface for LTC2209, 3.3V control signals, removed IC704** |
| **2.9** | **2026-01-25** | **Block 6: 3-stage RF choke, optimized de-Qing, new baluns** |

### **Version 2.9 Changes:**

1. **Block 6 RF Choke redesigned:** 3-stage instead of 2-stage for continuous coverage
   - L601/L604: 470uH (SWPA8065S471M) - LF coverage
   - L611/L612: 47uH (SWPA4030S470MT) - MF coverage (NEW)
   - L602/L603: 560nH (SWPA252010SR56NT) - HF coverage
2. **De-Qing resistors optimized:** R603=390 ohm, R620=82 ohm, R604=54 ohm
3. **Shunt resistors added:** R622/R623 (2.2k ohm) for C613/C614
4. **Baluns updated:** T601=TTWB-2-A (1:2), T602=CX2041NLT (1:1), BW=50kHz-200MHz
5. **Total DCR:** 1.86 ohm -> VCC=4.87V (within LTC6432 specification)

### **Version 2.8 Changes:**

1. **LTC2209 LVDS interface:** Replaced CMOS single-ended with LVDS differential
   - 16 differential data pairs (DA0-DA15, DB0-DB15)
   - 1 differential clock pair (CLKOUTA/CLKOUTB) on GC-capable IO1_7
   - DDR @ 153.6 MHz = 307.2 Mbps per lane
   - FPGA internal 100 ohm termination (DIFF_TERM_ADV TERM_100)
2. **ADC_OF moved to J901.21/22:** Overflow signal on 3.3V HR banks
3. **F2912 LOGICCTL=GND:** 3.3V logic mode for direct control from FPGA
4. **Removed IC704 (U704):** Level shifter no longer needed
5. **All control signals on J901:** DSA, FLT, RX_TX_MODE, I2C on 3.3V LVCMOS
6. **Updated J701 pinout:** LVDS interface only (17 differential pairs)

### **Version 2.7 Changes:**

1. **Atomic RX/TX control:** merged TX_RX_SWITCH and RX_TX_MODE into a single signal
2. **Single FPGA pin** (/RX_TX_MODE, J901.32) controls all RX/TX switching:
   - 3x F2912 RF switches (IC401-403.CTL2)
   - LTC2209 SHDN (direct 3.3V connection)
   - MAX5885 PD (via U902 inverter)
3. **Control current budget:** ~3.5 uA (margin >2000x from FPGA IOH/IOL)
4. **F2912 1-pin mode:** ModeCTL=VCC, LogicCTL=GND (3.3V logic)
5. **Pin 33 freed** for future use

### **Version 2.6 Changes:**

1. **Removed Block 10** (separate TX Driver no longer needed)
2. **Updated Block 4:** RF Switching instead of Power Control
   - IC401, IC402, IC403: F2912NCGI8 (SP3T RF switches)
   - RF switches control (updated to atomic in v2.7)
   - <100 ns switching time, >74 dB isolation
3. **Updated Block 9:** Correct DAC output stage topology
   - R903/R904 (25 ohm): DC return path for current-output DAC
   - Parallel decoupling: C915/C916 (1uF || 100nF), C917/C918 (1uF || 100nF)
   - T902: RF transformer with center tap bypass (C919)
4. **New TX architecture:** Shared RX/TX signal path through Block 2-3-5-6
   - TX signal: DAC -> IC401 -> Filter Bank -> LTC6432 -> IC402/IC403 -> TX Antenna
   - RX signal: Antenna -> Filter Bank -> LTC6432 -> IC402/IC403 -> ADC
5. **Power Management:** All blocks always on, ADC/DAC controlled via SHDN/PD pins
6. **Updated Block Structure table:** 9 blocks instead of 10

### **Version 2.5 Changes:**

1. **Added Block 9** (DAC & FPGA Interface for TX)
2. **IC901** MAX5885EGM+D: 16-bit DAC (153.6 MSPS update rate)
3. **Reference circuit:** R901 = 2k ohm -> Full-scale current 19.2 mA
4. **U901** LP5912-3.3DRV: Ultra-low noise LDO for DAC
5. **J901** 2x20 header: TX data/control interface to FPGA

### **Version 2.4 Changes:**

1. **Updated Block 7 documentation** with complete LTC2209 information
2. **Sample rate: 153.6 MSPS** (was 122.88 MHz -> now 153.6 MHz)
3. **Added Control Pins Configuration table** with rationale for each pin
4. **CMOS vs LVDS explanation:** Pin count limitation (J701 has only 40 pins)
5. **Dual Supply Architecture:** VDD=3.3V (analog), OVDD=1.8V (digital outputs)
6. **Mode rationale:** DITH=GND (better SNR), PGA=GND (gain=1)
7. **Updated all references from 122.88 MHz to 153.6 MHz** in the document

### **Version 2.3 Changes:**

1. **Added Block 8** (Clock Generation)
2. **IC801** Si5391B-A-GM: Ultra-low jitter clock generator (<50 fs RMS)
3. **X801** 38.4 MHz TCXO: Integer Mode reference (no fractional spurs)
4. **Dual LDO architecture:** U801 (1.8V) + U802 (3.3V) with LP5912 (12uVRMS noise)
5. **I2C programmability:** Address 0x68, ClockBuilder Pro configuration
6. **Output:** 122.88 MHz differential -> LTC2209 ADC clock input
7. **Power filtering:** Ferrite beads + decoupling capacitors for minimal jitter

### **Version 2.2 Changes:**

1. **Removed IC402** (74LVC1G04 inverter) from Block 4
2. **Software inversion in FPGA:** 2 pins (RX_TX_MODE, RX_TX_MODE_NOT)
3. **Improved reliability:** VOL = 0V, VOH = 1.8V (ideal margins)
4. **Updated J701 pinout:** Pin 32 (RX_TX_MODE), Pin 33 (RX_TX_MODE_NOT)

### **Version 2.1 Changes:**

1. **Added Block 4** (RX/TX Power Control and Indication Circuit)
2. **IC401** TPS22976DPUR: Dual-channel load switch for power management
3. **+5V_RX and +5V_TX rails:** separate power for RX and TX paths
4. **LED indication:** Green (RX mode), Blue (TX mode)

### **Version 2.0 Changes:**

1. **Removed Block 4** (PGA103+ LNA + bypass switches)
2. **Replaced IC601** from ADA4937-1YCPZ-R7 to **LTC6432AIUF-15#PBF**
3. **Added input balun T601** (ADT2-1T+ 1:2)
4. **Added output balun T602** (ADT2-1T+ 1:2) for VCM biasing
5. **Simplified architecture:** single chip instead of LNA + driver
6. **Fixed gain** +15.2 dB (no VGA needed)
7. **Improved power supply:** TPS7A2050 ultra-low noise LDO

---

## NEXT STEPS

### **Design Phase:**

- [ ] Create detailed documentation for each block
- [ ] Optimize output matching network Block 6
- [ ] Thermal analysis for LTC6432 (165mA @ 5V)

### **Verification:**

- [ ] SPICE simulation Block 6 (gain, IP3, noise)
- [ ] Power budget analysis (total current consumption)
- [ ] Signal integrity analysis (differential pairs)
- [ ] EMI/EMC considerations

### **Implementation:**

- [ ] PCB layout design (4-layer board)
- [ ] Component procurement
- [ ] Assembly + bring-up testing
- [ ] Performance characterization

---

## CONTACT & SUPPORT

**Datasheet Links:**

- LTC6432: [Analog Devices LTC6432 Product Page](https://www.analog.com/en/products/ltc6432.html)
- LTC2209: [Analog Devices LTC2209 Product Page](https://www.analog.com/en/products/ltc2209.html)
- PE43711A: [pSemi PE43711A Product Page](https://www.psemi.com/)
- PE42582A: [pSemi PE42582A Product Page](https://www.psemi.com/)

---

**End of Document**

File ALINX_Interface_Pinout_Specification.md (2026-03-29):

# ALINX AXU2CGB Interface Pinout Specification

## Project: SDR LTC2209 on ALINX AXU2CGB

**Date**: 2026-01-30
**Version**: 1.2

---

## 1. Overview

This document specifies the interface between the SDR project board and ALINX AXU2CGB FPGA development board. The design utilizes two 40-pin expansion connectors:

| Project Connector | ALINX Connector | FPGA Banks | I/O Voltage | Purpose |
| --- | --- | --- | --- | --- |
| **J701** | **J12** | BANK65, BANK66 | **1.2V** (HP) | LTC2209 LVDS Data Interface |
| **J901** | **J15** | BANK25, BANK26 | **3.3V** (HR) | Control Signals, ADC Status |

---

## 2. FPGA Bank Characteristics

### 2.1 HP Banks (High Performance) - J12

| Parameter | Value | Notes |
| --- | --- | --- |
| Banks | BANK65, BANK66 | Shared with MIPI interface  |
| VCCO | 1.2V | Set by PMIC |
| I/O Standards | LVDS, LVDS_25, LVCMOS12 | Native differential support |
| Max Frequency | 1.25 Gbps (LVDS) | Per Xilinx DS925 |
| Differential Pairs | 17 available on J12 | IO1_1 through IO1_17 |
| GC (Global Clock) Pairs | 3 pairs on J12 | IO1_6 (E5/D5), IO1_7 (D4/C4), IO1_11 (D7/D6) |

### 2.2 HR Banks (High Range) - J15

| Parameter | Value | Notes |
| --- | --- | --- |
| Banks | BANK25, BANK26 | General purpose I/O |
| VCCO | 3.3V | From LDO regulator  |
| I/O Standards  | LVCMOS33, LVCMOS25, LVCMOS18 | Single-ended only |
| Max Frequency  | 125 MHz (LVCMOS33) | Per Xilinx DS925 |
| Available Pins | 32 single-ended | Directly accessible |

---

## 3. J701 → J12 Pinout (LTC2209 LVDS Interface)

### 3.1 LTC2209 LVDS Mode Overview

In LVDS mode, LTC2209 outputs 16-bit data using **two parallel differential buses**:

- **Bus A (DA0-DA15)**: 16 lines forming 8 differential pairs
- **Bus B (DB0-DB15)**: 16 lines forming 8 differential pairs
- **Clock (CLKOUTA/CLKOUTB)**: 1 differential pair
- **Overflow (OFA/OFB)**: 1 differential pair

**Total LVDS requirement: 18 differential pairs**

**J12 availability: 17 differential pairs**

**Solution**: Move OF signal to J901 as single-ended 3.3V (use OFA only, tie OFB to ground on project board)

### 3.2 LTC2209 LVDS Pinout Reference

| LTC2209 Pin | CMOS Function | LVDS Function | Pair |
| --- | --- | --- | --- |
| 21 | D0- | DB0 | DB0/DB1 |
| 22 | D0+ | DB1 | |
| 23 | D1- | DB2 | DB2/DB3 |
| 24 | D1+ | DB3 | |
| 25 | D2- | DB4 | DB4/DB5 |
| 26 | D2+ | DB5 | |
| 27 | D3- | DB6 | DB6/DB7 |
| 28 | D3+ | DB7 | |
| 29 | D4- | DB8 | DB8/DB9 |
| 30 | D4+ | DB9 | |
| 33 | D5- | DB10 | DB10/DB11 |
| 34 | D5+ | DB11 | |
| 35 | D6- | DB12 | DB12/DB13 |
| 36 | D6+ | DB13 | |
| 37 | D7- | DB14 | DB14/DB15 |
| 38 | D7+ | DB15 | |
| 39 | CLKOUT- | OFB | - |
| 40 | CLKOUT+ | CLKOUTB | CLKOUTA/CLKOUTB |
| 41 | D8- | CLKOUTA | |
| 42 | D8+ | DA0 | DA0/DA1 |
| 43 | D9- | DA1 | |
| 44 | D9+ | DA2 | DA2/DA3 |
| 45 | D10- | DA3 | |
| 46 | D10+ | DA4 | DA4/DA5 |
| 47 | D11- | DA5 | |
| 48 | D11+ | DA6 | DA6/DA7 |
| 51 | D12- | DA7 | |
| 52 | D12+ | DA8 | DA8/DA9 |
| 53 | D13- | DA9 | |
| 54 | D13+ | DA10 | DA10/DA11 |
| 55 | D14- | DA11 | |
| 56 | D14+ | DA12 | DA12/DA13 |
| 57 | D15- | DA13 | |
| 58 | D15+ | DA14 | DA14/DA15 |
| 59 | OF- | DA15 | |
| 60 | OF+ | OFA | → J901 (single-ended) |

### 3.3 Differential Pair Mapping to J701/J12

| Netlist Signal  | LTC2209 Pins | J701 Pins | J12 Pins | FPGA Pair | FPGA Pins (P/N)  | GC? | Notes |
| --- | --- | --- | --- | --- | --- | --- | --- |
| ADC_D0_P/N | 22, 21 | 4, 3 | 4, 3 | IO1_1 | G8 (P), F7 (N)  | | DB0/DB1 (LVDS Bus B) |
| ADC_D1_P/N | 24, 23 | 6, 5 | 6, 5 | IO1_2 | G6 (P), F6 (N)  | | DB2/DB3 |
| ADC_D2_P/N | 26, 25 | 8, 7 | 8, 7 | IO1_3 | E9 (P), D9 (N)  | | DB4/DB5 |
| ADC_D3_P/N | 28, 27 | 10, 9 | 10, 9 | IO1_4 | G5 (P), F5 (N)  | | DB6/DB7 |
| ADC_D4_P/N | 30, 29 | 12, 11 | 12, 11 | IO1_5 | F8 (P), E8 (N)  | | DB8/DB9 |
| ADC_D5_P/N | 34, 33 | 14, 13 | 14, 13 | IO1_6 | E5 (P), D5 (N)  | **GC** | DB10/DB11, clock-capable |
| **ADC_DCO_P/N** | 40, 39 | 16, 15 | 16, 15 | IO1_7 | D4 (P), C4 (N)  | **GC** | **DCO Clock (current)** |
| ADC_D6_P/N | 36, 35 | 18, 17 | 18, 17 | IO1_8 | E4 (P), E3 (N)  | | DB12/DB13 |
| ADC_D7_P/N | 38, 37 | 20, 19 | 20, 19 | IO1_9 | G1 (P), F1 (N)  | | DB14/DB15 |
| ADC_D8_P/N | 42, 41 | 22, 21 | 22, 21 | IO1_10 | F2 (P), E2 (N)  | | DA0/DA1 (LVDS Bus A) |
| ADC_D9_P/N | 44, 43 | 24, 23 | 24, 23 | IO1_11 | D7 (P), D6 (N)  | **GC** | DA2/DA3, clock-capable+QBC |
| ADC_D10_P/N | 46, 45 | 26, 25 | 26, 25 | IO1_12 | C9 (P), B9 (N)  | | DA4/DA5 |
| ADC_D11_P/N | 48, 47 | 28, 27 | 28, 27 | IO1_13 | B4 (P), A4 (N)  | | DA6/DA7 |
| ADC_D12_P/N | 52, 51 | 30, 29 | 30, 29 | IO1_14 | C6 (P), B6 (N)  | | DA8/DA9 |
| ADC_D13_P/N | 54, 53 | 32, 31 | 32, 31 | IO1_15 | A7 (P), A6 (N)  | | DA10/DA11 |
| ADC_D14_P/N | 56, 55 | 34, 33 | 34, 33 | IO1_16 | C8 (P), B8 (N)  | | DA12/DA13 |
| ADC_D15_P/N | 58, 57 | 36, 35 | 36, 35 | IO1_17 | A9 (P), A8 (N)  | | DA14/DA15 |

### 3.4 J701/J12 Complete Pin Assignment

```
J701/J12 Connector (40-pin) — Corrected FPGA Pins per ALINX AXU2CGAB Manual
=============================================================================
GC = Global Clock capable pair (can drive BUFGCE/MMCM/PLL)

Pin 1  ────────────────── GND
Pin 2  ────────────────── VCC5V (5V from ALINX)
Pin 3  ──[ADC_D0_N]────── IO1_1_N  (F7)     ┐ Data pair 0
Pin 4  ──[ADC_D0_P]────── IO1_1_P  (G8)     ┘
Pin 5  ──[ADC_D1_N]────── IO1_2_N  (F6)     ┐ Data pair 1
Pin 6  ──[ADC_D1_P]────── IO1_2_P  (G6)     ┘
Pin 7  ──[ADC_D2_N]────── IO1_3_N  (D9)     ┐ Data pair 2
Pin 8  ──[ADC_D2_P]────── IO1_3_P  (E9)     ┘
Pin 9  ──[ADC_D3_N]────── IO1_4_N  (F5)     ┐ Data pair 3
Pin 10 ──[ADC_D3_P]────── IO1_4_P  (G5)     ┘
Pin 11 ──[ADC_D4_N]────── IO1_5_N  (E8)     ┐ Data pair 4
Pin 12 ──[ADC_D4_P]────── IO1_5_P  (F8)     ┘
Pin 13 ──[ADC_D5_N]────── IO1_6_N  (D5)     ┐ Data pair 5   ★ GC
Pin 14 ──[ADC_D5_P]────── IO1_6_P  (E5)     ┘               ★ Clock-Capable
Pin 15 ──[ADC_DCO_N]───── IO1_7_N  (C4)     ┐ DCO Clock     ★ GC
Pin 16 ──[ADC_DCO_P]───── IO1_7_P  (D4)     ┘               ★ Clock-Capable (current)
Pin 17 ──[ADC_D6_N]────── IO1_8_N  (E3)     ┐ Data pair 6
Pin 18 ──[ADC_D6_P]────── IO1_8_P  (E4)     ┘
Pin 19 ──[ADC_D7_N]────── IO1_9_N  (F1)     ┐ Data pair 7
Pin 20 ──[ADC_D7_P]────── IO1_9_P  (G1)     ┘   NOT clock-capable!
Pin 21 ──[ADC_D8_N]────── IO1_10_N (E2)     ┐ Data pair 8
Pin 22 ──[ADC_D8_P]────── IO1_10_P (F2)     ┘
Pin 23 ──[ADC_D9_N]────── IO1_11_N (D6)     ┐ Data pair 9   ★ GC+QBC
Pin 24 ──[ADC_D9_P]────── IO1_11_P (D7)     ┘               ★ Clock-Capable
Pin 25 ──[ADC_D10_N]───── IO1_12_N (B9)     ┐ Data pair 10
Pin 26 ──[ADC_D10_P]───── IO1_12_P (C9)     ┘
Pin 27 ──[ADC_D11_N]───── IO1_13_N (A4)     ┐ Data pair 11
Pin 28 ──[ADC_D11_P]───── IO1_13_P (B4)     ┘
Pin 29 ──[ADC_D12_N]───── IO1_14_N (B6)     ┐ Data pair 12
Pin 30 ──[ADC_D12_P]───── IO1_14_P (C6)     ┘
Pin 31 ──[ADC_D13_N]───── IO1_15_N (A6)     ┐ Data pair 13
Pin 32 ──[ADC_D13_P]───── IO1_15_P (A7)     ┘
Pin 33 ──[ADC_D14_N]───── IO1_16_N (B8)     ┐ Data pair 14
Pin 34 ──[ADC_D14_P]───── IO1_16_P (C8)     ┘
Pin 35 ──[ADC_D15_N]───── IO1_17_N (A8)     ┐ Data pair 15
Pin 36 ──[ADC_D15_P]───── IO1_17_P (A9)     ┘
Pin 37 ────────────────── GND
Pin 38 ────────────────── GND
Pin 39 ────────────────── VCC_3V3_BUCK4 (3.3V from ALINX)
Pin 40 ────────────────── VCC_3V3_BUCK4 (3.3V from ALINX)
```

### 3.5 Clock-Capable (GC) Pairs on J12

**IMPORTANT:** Only GC-designated FPGA pins can properly drive clock buffers (BUFGCE, MMCM, PLL).
The ADC DCO clock **must** be assigned to one of these pairs:

| J12 Pins | FPGA Pair | FPGA Pins (P/N) | Full Xilinx Pin Name | Currently Assigned |
| --- | --- | --- | --- | --- |
| 13, 14 | IO1_6 | E5 (P), D5 (N)  | IO_L14P/N_T2L_N2_GC_66 | ADC_D5 (data) |
| **15, 16** | **IO1_7** | **D4 (P), C4 (N)** | **IO_L11P/N_T1U_N8_GC_66** | **ADC_DCO (clock)** |
| 23, 24 | IO1_11 | D7 (P), D6 (N)  | IO_L13P/N_T2L_N0_GC_QBC_66 | ADC_D9 (data) |

All other J12 pairs (IO1_1-IO1_5, IO1_8-IO1_10, IO1_12-IO1_17) are **regular I/O** — NOT clock-capable.
Pins 19/20 (IO1_9, G1/F1 = `IO_L1P/N_T0L_N0_DBC_66`) are **NOT GC** and must NOT carry the DCO clock.

### 3.5 Pair Utilization Summary

| Resource | Available | Used | Free |
| --- | --- | --- | --- |
| Differential pairs on J12 | 17 | 17 | 0 |
| - Clock pair (GC) | 1 | 1 | 0 |
| - Data pairs | 16 | 16 | 0 |
| Overflow (OF) | - | → J901 | Single-ended |

**Note**: All 17 differential pairs on J12 are utilized. Overflow signal moved to J901

---

## 4. J901 → J15 Pinout (Control Signals, 3.3V)

### 4.1 Control Signal Mapping

| Signal | J901 Pin | J15 Pin | Function | Destination IC | Series R |
| --- | --- | --- | --- | --- | --- |
| ADC_OF_P | 21 | 21 | Overflow+ (OFA) | LTC2209.60 | 47Ω |
| ADC_OF_N | 22 | 22 | Overflow- (OF-) | LTC2209.59 | 47Ω |
| DSA_LE1 | 24 | 24 | Latch Enable 1 | PE43711 #1 | 47Ω |
| DSA_LE2 | 25 | 25 | Latch Enable 2 | PE43711 #2 | 47Ω |
| DSA_DATA | 26 | 26 | SPI Data | PE43711 | 47Ω |
| DSA_SCLK | 27 | 27 | SPI Clock | PE43711 | 47Ω |
| FLT_V1 | 28 | 28 | Filter Select 1 | PE42582A | 47Ω |
| FLT_V2 | 29 | 29 | Filter Select 2 | PE42582A | 47Ω |
| FLT_V3 | 30 | 30 | Filter Select 3 | PE42582A | 47Ω |
| FLT_V4 | 31 | 31 | Filter Select 4 | PE42582A | 47Ω |
| RX_TX_MODE | 32 | 32 | TX/RX Control | F2912, LTC2209 | 47Ω |
| I2C_SDA | 33 | 33 | I2C Data | Si5391B | None\* |
| I2C_SCL | 34 | 34 | I2C Clock | Si5391B | None\* |

\*I2C lines are open-drain with external pull-ups - no series resistors

**Note**: RX_TX_MODE (3.3V) directly controls F2912 RF switches (LOGICCTL=GND mode) and LTC2209 SHDN pin.

### 4.2 J901/J15 Complete Pin Assignment

```
J901/J15 Connector (40-pin) - Control Signals (3.3V LVCMOS)
===========================================================

Pin 1  ────────────── GND
Pin 2  ────────────── VCC (3.3V)
Pin 3  ────────────── Reserved (DAC interface)
Pin 4  ────────────── Reserved (DAC interface)
Pin 5  ────────────── Reserved (DAC interface)
Pin 6  ────────────── Reserved (DAC interface)
Pin 7  ────────────── Reserved (DAC interface)
Pin 8  ────────────── Reserved (DAC interface)
Pin 9  ────────────── Reserved (DAC interface)
Pin 10 ────────────── Reserved (DAC interface)
Pin 11 ────────────── Reserved (DAC interface)
Pin 12 ────────────── Reserved (DAC interface)
Pin 13 ────────────── Reserved (DAC interface)
Pin 14 ────────────── Reserved (DAC interface)
Pin 15 ────────────── Reserved (DAC interface)
Pin 16 ────────────── Reserved (DAC interface)
Pin 17 ────────────── Reserved (DAC interface)
Pin 18 ────────────── Reserved (DAC interface)
Pin 19 ────────────── Reserved
Pin 20 ────────────── Reserved
Pin 21 ──[ADC_OF_P]── BANK25/26 (Overflow+, LTC2209.60)
Pin 22 ──[ADC_OF_N]── BANK25/26 (Overflow-, LTC2209.59)
Pin 23 ────────────── Reserved
Pin 24 ──[DSA_LE1]─── BANK25/26 (PE43711 #1 Latch Enable)
Pin 25 ──[DSA_LE2]─── BANK25/26 (PE43711 #2 Latch Enable)
Pin 26 ──[DSA_DATA]── BANK25/26 (DSA SPI Data)
Pin 27 ──[DSA_SCLK]── BANK25/26 (DSA SPI Clock)
Pin 28 ──[FLT_V1]──── BANK25/26 (Filter Select Bit 0)
Pin 29 ──[FLT_V2]──── BANK25/26 (Filter Select Bit 1)
Pin 30 ──[FLT_V3]──── BANK25/26 (Filter Select Bit 2)
Pin 31 ──[FLT_V4]──── BANK25/26 (Filter Select Bit 3)
Pin 32 ──[RX_TX_MODE] BANK25/26 (TX/RX Mode Control)
Pin 33 ──[I2C_SDA]─── BANK25/26 (Si5391B I2C Data)
Pin 34 ──[I2C_SCL]─── BANK25/26 (Si5391B I2C Clock)
Pin 35 ────────────── Reserved
Pin 36 ────────────── Reserved
Pin 37 ────────────── GND
Pin 38 ────────────── GND
Pin 39 ────────────── VCC (3.3V)
Pin 40 ────────────── VCC (3.3V)
```

---

## 5. Vivado XDC Constraints

### 5.1 LTC2209 LVDS Interface (J12, BANK65/66)

```tcl
# =============================================================================
# LTC2209 LVDS Interface - ALINX AXU2CGB J12 Connector
# BANK65/66 (HP Banks) - VCCO = 1.2V
# Pin numbers verified against ALINX AXU2CGAB User Manual (2026-01-30)
# =============================================================================

# -----------------------------------------------------------------------------
# DCO Clock Input (MUST be on GC-capable pins IO1_7)
# IO_L11P/N_T1U_N8_GC_66 — Global Clock pair in BANK66
# -----------------------------------------------------------------------------
set_property PACKAGE_PIN D4 [get_ports adc_dco_p]
set_property PACKAGE_PIN C4 [get_ports adc_dco_n]
set_property IOSTANDARD LVDS [get_ports adc_dco_p]
set_property IOSTANDARD LVDS [get_ports adc_dco_n]
set_property DIFF_TERM_ADV TERM_100 [get_ports adc_dco_p]

# DCO Clock Constraint (153.6 MHz from LTC2209)
create_clock -period 6.510 -name adc_dco_clk [get_ports adc_dco_p]

# -----------------------------------------------------------------------------
# LVDS Data Bus D[15:0] — 16 differential pairs
# -----------------------------------------------------------------------------
# D0 - IO1_1 (J12 pins 3/4)
set_property PACKAGE_PIN G8 [get_ports {adc_data_p[0]}]
set_property PACKAGE_PIN F7 [get_ports {adc_data_n[0]}]

# D1 - IO1_2 (J12 pins 5/6)
set_property PACKAGE_PIN G6 [get_ports {adc_data_p[1]}]
set_property PACKAGE_PIN F6 [get_ports {adc_data_n[1]}]

# D2 - IO1_3 (J12 pins 7/8)
set_property PACKAGE_PIN E9 [get_ports {adc_data_p[2]}]
set_property PACKAGE_PIN D9 [get_ports {adc_data_n[2]}]

# D3 - IO1_4 (J12 pins 9/10)
set_property PACKAGE_PIN G5 [get_ports {adc_data_p[3]}]
set_property PACKAGE_PIN F5 [get_ports {adc_data_n[3]}]

# D4 - IO1_5 (J12 pins 11/12)
set_property PACKAGE_PIN F8 [get_ports {adc_data_p[4]}]
set_property PACKAGE_PIN E8 [get_ports {adc_data_n[4]}]

# D5 - IO1_6 (J12 pins 13/14) ★ GC-capable (IO_L14_GC_66)
set_property PACKAGE_PIN E5 [get_ports {adc_data_p[5]}]
set_property PACKAGE_PIN D5 [get_ports {adc_data_n[5]}]

# D6 - IO1_8 (J12 pins 17/18)
set_property PACKAGE_PIN E4 [get_ports {adc_data_p[6]}]
set_property PACKAGE_PIN E3 [get_ports {adc_data_n[6]}]

# D7 - IO1_9 (J12 pins 19/20) — NOT clock-capable
set_property PACKAGE_PIN G1 [get_ports {adc_data_p[7]}]
set_property PACKAGE_PIN F1 [get_ports {adc_data_n[7]}]

# D8 - IO1_10 (J12 pins 21/22)
set_property PACKAGE_PIN F2 [get_ports {adc_data_p[8]}]
set_property PACKAGE_PIN E2 [get_ports {adc_data_n[8]}]

# D9 - IO1_11 (J12 pins 23/24) ★ GC-capable (IO_L13_GC_QBC_66)
set_property PACKAGE_PIN D7 [get_ports {adc_data_p[9]}]
set_property PACKAGE_PIN D6 [get_ports {adc_data_n[9]}]

# D10 - IO1_12 (J12 pins 25/26)
set_property PACKAGE_PIN C9 [get_ports {adc_data_p[10]}]
set_property PACKAGE_PIN B9 [get_ports {adc_data_n[10]}]

# D11 - IO1_13 (J12 pins 27/28)
set_property PACKAGE_PIN B4 [get_ports {adc_data_p[11]}]
set_property PACKAGE_PIN A4 [get_ports {adc_data_n[11]}]

# D12 - IO1_14 (J12 pins 29/30)
set_property PACKAGE_PIN C6 [get_ports {adc_data_p[12]}]
set_property PACKAGE_PIN B6 [get_ports {adc_data_n[12]}]

# D13 - IO1_15 (J12 pins 31/32)
set_property PACKAGE_PIN A7 [get_ports {adc_data_p[13]}]
set_property PACKAGE_PIN A6 [get_ports {adc_data_n[13]}]

# D14 - IO1_16 (J12 pins 33/34)
set_property PACKAGE_PIN C8 [get_ports {adc_data_p[14]}]
set_property PACKAGE_PIN B8 [get_ports {adc_data_n[14]}]

# D15 - IO1_17 (J12 pins 35/36)
set_property PACKAGE_PIN A9 [get_ports {adc_data_p[15]}]
set_property PACKAGE_PIN A8 [get_ports {adc_data_n[15]}]

# Apply LVDS standard and termination to all data pins
set_property IOSTANDARD LVDS [get_ports adc_data_p[*]]
set_property IOSTANDARD LVDS [get_ports adc_data_n[*]]
set_property DIFF_TERM_ADV TERM_100 [get_ports adc_data_p[*]]

# -----------------------------------------------------------------------------
# Timing Constraints for LVDS Data
# -----------------------------------------------------------------------------
# DDR data is center-aligned with DCO clock
set_input_delay -clock adc_dco_clk -max 0.5 [get_ports adc_data_p[*]]
set_input_delay -clock adc_dco_clk -min -0.5 [get_ports adc_data_p[*]]
set_input_delay -clock adc_dco_clk -max 0.5 -clock_fall [get_ports adc_data_p[*]] -add_delay
set_input_delay -clock adc_dco_clk -min -0.5 -clock_fall [get_ports adc_data_p[*]] -add_delay
```

### 5.2 Control Signals (J15, BANK25/26)

```tcl
# =============================================================================
# Control Signals - ALINX AXU2CGB J15 Connector
# BANK25/26 (HR Banks) - VCCO = 3.3V
# =============================================================================

# -----------------------------------------------------------------------------
# PE43711 DSA SPI Interface
# -----------------------------------------------------------------------------
set_property PACKAGE_PIN [TBD] [get_ports dsa_sclk]
set_property PACKAGE_PIN [TBD] [get_ports dsa_data]
set_property PACKAGE_PIN [TBD] [get_ports dsa_le1]
set_property PACKAGE_PIN [TBD] [get_ports dsa_le2]
set_property IOSTANDARD LVCMOS33 [get_ports dsa_*]
set_property SLEW SLOW [get_ports dsa_*]
set_property DRIVE 4 [get_ports dsa_*]

# -----------------------------------------------------------------------------
# LTC2209 I2C Interface
# -----------------------------------------------------------------------------
set_property PACKAGE_PIN [TBD] [get_ports i2c_scl]
set_property PACKAGE_PIN [TBD] [get_ports i2c_sda]
set_property IOSTANDARD LVCMOS33 [get_ports i2c_*]
set_property PULLUP TRUE [get_ports i2c_*]

# -----------------------------------------------------------------------------
# Filter Control
# -----------------------------------------------------------------------------
set_property PACKAGE_PIN [TBD] [get_ports {flt_v[0]}]
set_property PACKAGE_PIN [TBD] [get_ports {flt_v[1]}]
set_property PACKAGE_PIN [TBD] [get_ports {flt_v[2]}]
set_property PACKAGE_PIN [TBD] [get_ports {flt_v[3]}]
set_property IOSTANDARD LVCMOS33 [get_ports flt_v[*]]
set_property SLEW SLOW [get_ports flt_v[*]]
set_property DRIVE 4 [get_ports flt_v[*]]

# -----------------------------------------------------------------------------
# RX/TX Mode Control
# -----------------------------------------------------------------------------
set_property PACKAGE_PIN [TBD] [get_ports rx_tx_mode]
set_property IOSTANDARD LVCMOS33 [get_ports rx_tx_mode]
set_property SLEW SLOW [get_ports rx_tx_mode]
set_property DRIVE 4 [get_ports rx_tx_mode]

# -----------------------------------------------------------------------------
# ADC Overflow Status (LTC2209 OF+/OF- on J901.21/22)
# -----------------------------------------------------------------------------
set_property PACKAGE_PIN [TBD] [get_ports adc_of_p]
set_property PACKAGE_PIN [TBD] [get_ports adc_of_n]
set_property IOSTANDARD LVCMOS33 [get_ports adc_of_p]
set_property IOSTANDARD LVCMOS33 [get_ports adc_of_n]
```

---

## 6. Interface Block Diagram

```
┌─────────────────────────────────────────────────────────────────────────────┐
│                          SDR PROJECT BOARD                                   │
│                                                                              │
│  ┌──────────┐    ┌──────────┐    ┌──────────┐    ┌──────────┐              │
│  │ LTC2209  │    │ PE43711  │    │ PE43711  │    │  F2912   │              │
│  │   ADC    │    │  DSA #1  │    │  DSA #2  │    │ Switches │              │
│  │  (LVDS)  │    │          │    │          │    │  (×3)    │              │
│  └────┬─────┘    └────┬─────┘    └────┬─────┘    └────┬─────┘              │
│       │               │               │               │                     │
│       │ LVDS          │ SPI           │ SPI           │ CTL (3.3V)          │
│       │ (17 pairs)    │               │               │ LOGICCTL=GND        │
│       │               │               │               │                     │
│  ┌────┴────┐     ┌────┴───────────────┴───────────────┴────┐               │
│  │  J701   │     │                   J901                   │               │
│  │ (40pin) │     │                 (40pin)                  │               │
│  │         │     │                                          │               │
│  │ LVDS:   │     │ ADC_OF_P ──[47Ω]──→ LTC2209.60          │               │
│  │ DA0-15  │     │ ADC_OF_N ──[47Ω]──→ LTC2209.59          │               │
│  │ DB0-15  │     │ DSA_SCLK ──[47Ω]──→ PE43711             │               │
│  │ DCO     │     │ DSA_DATA ──[47Ω]──→ PE43711             │               │
│  │ (17     │     │ DSA_LE1  ──[47Ω]──→ PE43711 #1          │               │
│  │ pairs)  │     │ DSA_LE2  ──[47Ω]──→ PE43711 #2          │               │
│  │         │     │ FLT_V1-4 ──[47Ω]──→ PE42582A            │               │
│  │         │     │ RX_TX    ──[47Ω]──→ F2912, LTC2209.SHDN │               │
│  │         │     │ I2C_SCL  ─────────→ Si5391B (no R)      │               │
│  │         │     │ I2C_SDA  ─────────→ Si5391B (no R)      │               │
│  └────┬────┘     └────────────────────┬────────────────────┘               │
│       │                               │                                     │
└───────┼───────────────────────────────┼─────────────────────────────────────┘
        │                               │
        │ 40-pin cable                  │ 40-pin cable
        │                               │
┌───────┼───────────────────────────────┼─────────────────────────────────────┐
│       │                               │                                     │
│  ┌────┴────┐                     ┌────┴────┐                               │
│  │   J12   │                     │   J15   │                               │
│  │ (40pin) │                     │ (40pin) │                               │
│  └────┬────┘                     └────┬────┘                               │
│       │                               │                                     │
│       │                               │                                     │
│  ┌────┴────────────┐            ┌────┴────────────┐                        │
│  │   BANK65/66     │            │   BANK25/26     │                        │
│  │   (HP Banks)    │            │   (HR Banks)    │                        │
│  │   VCCO = 1.2V   │            │   VCCO = 3.3V   │                        │
│  │                 │            │                 │                        │
│  │   Native LVDS   │            │   LVCMOS33      │                        │
│  │   100Ω int.term │            │   Single-ended  │                        │
│  │   (DIFF_TERM)   │            │                 │                        │
│  └────────┬────────┘            └────────┬────────┘                        │
│           │                              │                                  │
│           └──────────────┬───────────────┘                                  │
│                          │                                                  │
│               ┌──────────┴──────────┐                                       │
│               │   XCZU2CG-1SFVC784E │                                       │
│               │   Zynq UltraScale+  │                                       │
│               └─────────────────────┘                                       │
│                                                                             │
│                      ALINX AXU2CGB                                          │
└─────────────────────────────────────────────────────────────────────────────┘
```

---

## 7. Signal Integrity Considerations

### 7.1 LVDS Interface (J701 → J12)

| Parameter | Specification | Notes |
| --- | --- | --- |
| Differential Impedance | 100Ω ± 10% | Controlled impedance PCB traces |
| Trace Length Matching  | ≤ 5mm within pair | Critical for signal integrity |
| Maximum Trace Length | 150mm | LTC2209 to FPGA |
| Termination | 100Ω on-die | FPGA internal DIFF_TERM |
| Common Mode Voltage | 1.2V nominal | Set by LTC2209 driver |

### 7.2 Control Signals (J901 → J15)

| Parameter | Specification | Notes |
| --- | --- | --- |
| Logic Level | 3.3V LVCMOS | Compatible with all target ICs |
| Series Resistor | 47Ω | Edge rate control, ESD protection |
| Noise Margin | 1.0V (high), 0.8V (low) | Excellent noise immunity |
| Maximum Frequency | 10 MHz (SPI) | Well within LVCMOS33 capability |
| I2C Pull-ups | 4.7kΩ to 3.3V | Standard I2C specification |

---

## 8. PCB Design Guidelines

### 8.1 LVDS Traces

1. Route P and N traces as tightly coupled differential pairs
2. Maintain 100Ω differential impedance
3. Length match P and N within 0.5mm
4. Avoid vias in differential pairs where possible
5. Keep differential pairs at least 3x trace width apart
6. Route DCO pair with same length as data pairs (±5mm)

### 8.2 Control Signal Traces

1. Place 47Ω series resistors within 10mm of connector
2. Avoid parallel routing with LVDS pairs
3. I2C traces: keep under 100mm, add 4.7kΩ pull-ups near FPGA
4. Ground plane under all signal traces

---

## 9. Summary of Design

### 9.1 J701/J12 Interface (LVDS, 1.2V HP Banks)

| Resource | Count | Description |
| --- | ----- | --- |
| Data Pairs (DA/DB)  | 16 | DA0-DA15 + DB0-DB15 (16-bit DDR) |
| Clock Pair (DCO) | 1 | CLKOUTA/CLKOUTB on GC-capable IO1_7 |
| **Total LVDS Pairs**| 17 | All J12 differential pairs utilized |
| FPGA Termination | 100Ω  | Internal (DIFF_TERM_ADV TERM_100) |

### 9.2 J901/J15 Interface (3.3V HR Banks)

| Signal | J901 Pin | Function |
| --- | --- | --- |
| ADC_OF_P/N  | 21, 22 | LTC2209 Overflow (pins 60/59) |
| DSA_LE1/2 | 24, 25 | PE43711 Latch Enable (SPI chip select) |
| DSA_DATA | 26 | PE43711 SPI Data (shared) |
| DSA_SCLK | 27 | PE43711 SPI Clock (shared) |
| FLT_V1-V4 | 28-31 | PE42582A Filter Bank Select (4-bit) |
| RX_TX_MODE  | 32 | F2912 switches + LTC2209 SHDN (3.3V) |
| I2C_SDA/SCL | 33, 34 | Si5391B I2C Configuration |

### 9.3 ADC Interface Configuration

| Parameter | Value |
| --- | --- |
| Interface Type | LVDS Differential |
| Data Lines | 16 differential pairs (DA0-15 + DB0-15) |
| Clock | 1 differential pair (CLKOUTA/CLKOUTB) |
| Data Rate | DDR at 153.6 MHz = 307.2 Mbps per pair |
| Overflow (OF) | Single-ended on J901 (pins 21/22) |
| FPGA Termination | 100Ω internal (DIFF_TERM_ADV TERM_100) |
| LTC2209 LVDS | VOS = 1.2V, VOD = 350mV (compatible with HP 1.2V)|

---

## 10. Revision History

| Version | Date | Changes |
| --- | --- | --- |
| 1.0 | 2026-01-25 | Initial specification |
| 1.1 | 2026-01-25 | Updated ADC_OF to J901.21/22, corrected control signal table |
| 1.2 | 2026-01-30 | Fixed all FPGA ball numbers per ALINX manual; added 3 GC clock-capable pairs; updated signal names to match netlist; updated XDC constraints |

---

## 11. References

1. ALINX AXU2CGAB User Manual
2. ALINX AXU2CGA_B Schematic (Rev 1.0)
3. Xilinx UltraScale+ Device Data Sheet (DS925)
4. Linear Technology LTC2209 Datasheet
5. Peregrine PE43711 Datasheet

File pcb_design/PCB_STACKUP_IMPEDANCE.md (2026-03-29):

# PCB Stackup & Impedance Control

**Project:** SDR Receiver/Transceiver LTC2209
**PCB Manufacturer:** JLCPCB
**Stackup ID:** JLC06161H-7628

---

## Board Specifications

| Parameter | Value |
| --- | --- |
| Layers | 6 |
| Total Thickness | 1.6 mm |
| Material | FR4 TG155 (NP-155F) |
| Outer Copper | 1 oz = 0.035 mm (35 µm) |
| Inner Copper | 0.5 oz = **0.0152 mm** (15.2 µm) |
| Surface Finish  | HASL / ENIG |

**Important:** Inner copper thickness per JLCPCB is 0.0152 mm, not theoretical 17.5 µm (0.0175 mm).

---

## Layer Stackup (JLC06161H-7628 based, 1.6mm)

**Source:** [JLCPCB Impedance Calculator](https://jlcpcb.com/impedance)

```
┌─────────────────────────────────────────────────────────────────┐
│  Solder Mask (Top)                              ~0.02 mm        │
├─────────────────────────────────────────────────────────────────┤
│  L1: Signal (RF/Analog)         Cu: 0.035 mm   ← RF, LNA, DSA   │
├─────────────────────────────────────────────────────────────────┤
│  Prepreg 7628                   H1: 0.2104 mm   εr = 4.4        │
├─────────────────────────────────────────────────────────────────┤
│  L2: GND (Solid)                Cu: 0.0152 mm  ← Reference L1   │
├─────────────────────────────────────────────────────────────────┤
│  Core                           H2: 0.4 mm     εr = 4.6        │
├─────────────────────────────────────────────────────────────────┤
│  L3: Signal/Power               Cu: 0.0152 mm  ← +5V, Control   │
├─────────────────────────────────────────────────────────────────┤
│  Prepreg 7628                   H3: 0.2028 mm   εr = 4.4        │
├─────────────────────────────────────────────────────────────────┤
│  L4: Signal/Power               Cu: 0.0152 mm  ← Digital aux    │
├─────────────────────────────────────────────────────────────────┤
│  Core                           H4: 0.4 mm     εr = 4.6        │
├─────────────────────────────────────────────────────────────────┤
│  L5: GND (Solid)                Cu: 0.0152 mm  ← Reference L6   │
├─────────────────────────────────────────────────────────────────┤
│  Prepreg 7628                   H5: 0.2104 mm   εr = 4.4        │
├─────────────────────────────────────────────────────────────────┤
│  L6: Signal (Digital)           Cu: 0.035 mm   ← ADC, DAC, LVDS │
├─────────────────────────────────────────────────────────────────┤
│  Solder Mask (Bottom)                           ~0.02 mm        │
└─────────────────────────────────────────────────────────────────┘
```

**Note:** Copper thicknesses from JLCPCB specs:

- Outer layers (L1, L6): 1oz = 0.035 mm (35 µm)
- Inner layers (L2-L5): 0.5oz = **0.0152 mm** (15.2 µm) — JLCPCB actual value

---

## Layer Assignment

| Layer | Type | Content | Reference | Line Type  |
| ----- | --- | --- | --- | --- |
| L1 | Signal | RF filters, DSA1, DSA2, LTC6432 (LNA), LDOs | L2 (GND) | Microstrip |
| L2 | GND | Solid ground plane (analog shield) | — | — |
| L3 | Signal | Digital signals, RF, ADC_OF differential pair | L2 (GND) + L4 (+5V) | **Stripline** |
| L4 | Power  | +5V power plane (AC ground) | — | — |
| L5 | GND | Solid ground plane (digital shield) | — | — |
| L6 | Signal | LTC2209 (ADC), MAX5885 (DAC), Si5391B, LVDS pairs | L5 (GND) | Microstrip |

**Note:** L3 is an **Offset Stripline** — traces between two reference planes (L2=GND, L4=+5V).
L4 (+5V) acts as AC ground when properly decoupled with bypass capacitors.

---

## Dielectric Properties

| Material | Thickness | Dk (εr) | Df (tan δ) |
| --- | --- | --- | --- |
| Prepreg 7628 (H1, H5) | 0.2104 mm | 4.4 | 0.02 |
| Prepreg 7628 (H3) | 0.2028 mm | 4.4 | 0.02 |
| Core FR4 (H2, H4) | ~0.4 mm | 4.6 | 0.02 |
| Solder Mask | ~0.02 mm  | 3.8 | — |

**Note:** Core thickness adjusted for 1.6 mm total board thickness.

---

## Impedance Targets

| Signal Type | Target Z | Location | Line Type |
| --- | --- | --- | --- |
| RF Single-ended | 50Ω | L1 (RF path) | CPWG Microstrip |
| LVDS Differential | 100Ω | L6 (ADC data) | Edge-coupled CPWG |
| Clock Differential | 100Ω | L6 (Si5391B → ADC) | Edge-coupled CPWG |
| CMOS Digital | 50Ω | L6 (DAC data) | CPWG Microstrip |
| **Digital/RF on L3** | **50Ω**  | **L3 (control, RF)**  | **Stripline**  |
| **Differential on L3** | **100Ω** | **L3 (ADC_OF pair)**  | **Coupled Stripline** |

---

## Track Geometry Calculations

### Reference Parameters (L1/L6 to GND)

- **H** (dielectric height): 0.2104 mm (prepreg 7628)
- **T** (outer copper): 0.035 mm (1oz)
- **T** (inner copper): 0.0152 mm (0.5oz per JLCPCB)
- **εr** (prepreg): 4.4
- **εr** (core): 4.6

---

### 50Ω Single-Ended (Coplanar Waveguide with Ground - CPWG)

For RF traces on L1 with GND pour and L2 as reference:

**Calculated with KiCad PCB Calculator:**

| W (trace) | Sg (gap to GND pour) | Z0 |
| --- | --- | --- |
| 0.30 mm | 0.15 mm | ~48Ω |
| **0.36 mm** | **0.20 mm** | **50Ω** ✓ |
| 0.40 mm | 0.25 mm | ~52Ω |

**Recommended:** W = 0.36 mm, Sg = 0.20 mm

```
Cross-section (CPWG Single-Ended):

      Sg        W        Sg
    ┌────┐  ┌──────┐  ┌────┐
    │GND │  │Signal│  │GND │   ← L1 (Top)
════╧════╧══╧══════╧══╧════╧════
─────────────────────────────── ← L2 (GND plane, H = 0.2104 mm)
```

**Nets:**

- RF_IN (J101 → T101)
- DSA1_IN, DSA1_OUT
- RF_FILTR_IN_x, RF_FILTR_OUT_x
- DSA2_IN, DSA2_OUT
- RF_1 (to LTC6432)
- F2912 switch paths

---

### 100Ω Differential (Edge-Coupled CPWG)

For LVDS pairs on L6 with L5 as reference:

**Parameters:**

- **W** — trace width (ширина доріжки)
- **S** — gap between differential pair traces (gap між парою)
- **Sg** — gap from traces to GND pour (gap до заливки землі)

**Calculated values:**

| W (trace) | S (pair gap) | Sg (to GND pour) | Zdiff |
| --- | --- | --- | --- |
| 0.15 mm | 0.15 mm | 0.15 mm | ~95Ω |
| 0.18 mm | 0.15 mm | 0.20 mm | ~98Ω |
| **0.20 mm** | **0.15 mm**  | **0.20 mm** | **~100Ω** ✓ |
| 0.20 mm | 0.20 mm | 0.20 mm | ~105Ω |

**Recommended:** W = 0.20 mm, S = 0.15 mm, Sg = 0.20 mm

```
Cross-section (Edge-Coupled CPWG Differential):

     Sg       W     S      W      Sg
   ┌────┐ ┌─────┐     ┌─────┐ ┌────┐
   │GND │ │  +  │     │  -  │ │GND │   ← L6 (Bottom)
═══╧════╧═╧═════╧═════╧═════╧═╧════╧═══
─────────────────────────────────────── ← L5 (GND plane, H = 0.2104 mm)

W  = 0.20 mm  (trace width)
S  = 0.15 mm  (gap between + and -)
Sg = 0.20 mm  (gap to GND pour on sides)
```

**Nets:**

- DA0±...DA15± (ADC Bus A)
- DB0±...DB15± (ADC Bus B)
- CLKOUTA/CLKOUTB (ADC clock output)
- CLK_0/CLK_B (Si5391B → ADC clock input)
- ADC_P_OUT/ADC_N_OUT (LTC6432 → ADC)

---

### 50Ω Single-Ended Digital (CMOS on L6)

For DAC data bus (TX_D0-TX_D15):

| W (trace) | Sg (gap to GND pour) | Z0 |
| --- | --- | --- |
| 0.30 mm | 0.15 mm | ~48Ω |
| **0.36 mm** | **0.20 mm** | **50Ω** ✓ |

**Recommended:** W = 0.36 mm, Sg = 0.20 mm (same as RF)

**Nets:**

- TX_D0...TX_D15
- TX_SEL0, TX_XOR
- DSA_SCLK, DSA_DATA, DSA_LE1, DSA_LE2
- FLT_V1...FLT_V4
- RX_TX_MODE

---

## L3 Stripline Calculations

### Why L3 is Different

L3 is located **between two reference planes**:
- **L2 (GND)** — above, distance H1 = 0.4 mm (core)
- **L4 (+5V)** — below, distance H2 = 0.2028 mm (prepreg)

This creates an **Offset Stripline** geometry, which has different impedance characteristics than Microstrip (L1/L6).

```
L2: GND (solid)     ════════════════════════════════════
                           ↑ H1 = 0.4 mm (core, εr = 4.6)
L3: Signal          ───────────────────────────────────
                           ↓ H2 = 0.2028 mm (prepreg, εr = 4.4)
L4: +5V (solid)     ════════════════════════════════════
                              (AC ground with bypass caps)
```

### Reference Parameters (L3 Stripline)

**Calculated with KiCad PCB Calculator (Stripline mode):**

| Parameter | Value | Description |
|---|---|---|
| εr | 4.5 | Average dielectric constant |
| tan δ | 0.02 | Loss tangent |
| H | 0.618 mm | Total height (H1 + H2 + T) |
| a | 0.4 mm | Offset (distance to L2) |
| T | 0.0152 mm | Copper thickness (inner) |

---

### 50Ω Single-Ended (Stripline on L3)

**Calculated with KiCad PCB Calculator:**

| W (trace) | Z0 (stripline) |
|---|---|
| 0.18 mm | ~55Ω |
| **0.22 mm** | **50Ω** ✓ |
| 0.25 mm | ~45Ω |

**Recommended:** W = 0.22 mm

```
Cross-section (Offset Stripline Single-Ended):

L2: GND ════════════════════════════════
              ↑ H1 = 0.4 mm

L3:         ┌─────┐
            │ SIG │  W = 0.22 mm
            └─────┘

              ↓ H2 = 0.2028 mm
L4: +5V ════════════════════════════════
```

**Nets on L3 (Single-Ended):**

- Control signals routed on L3
- RF signals between switches (if any)
- Digital signals that didn't fit on L1/L6

---

### 100Ω Differential (Coupled Stripline on L3)

For ADC_OF differential pair on L3:

**Estimated values (coupled stripline):**

| W (trace) | S (pair gap) | Zdiff |
|---|---|---|
| 0.12 mm | 0.12 mm | ~105Ω |
| **0.15 mm** | **0.12 mm** | **~100Ω** ✓ |
| 0.15 mm | 0.15 mm | ~95Ω  |

**Recommended:** W = 0.15 mm, S = 0.12 mm

```
Cross-section (Coupled Stripline Differential):

L2: GND ════════════════════════════════════════
                 ↑ H1 = 0.4 mm

L3:           ┌─────┐     ┌─────┐
              │  +  │     │  -  │   W = 0.15 mm, S = 0.12 mm
              └─────┘     └─────┘

                 ↓ H2 = 0.2028 mm
L4: +5V ════════════════════════════════════════
```

**Nets on L3 (Differential):**

- ADC_OF_P / ADC_OF_N (overflow pair routed partially on L3)

---

### L3 Pour Recommendation

**Option: No Pour (Recommended for simplicity)**

Since L3 is already sandwiched between two solid planes (L2=GND, L4=+5V), additional pour is not strictly necessary for impedance control.

**If Pour is desired:**
- Use **GND pour** connected to L2 via stitching vias
- Clearance (Sg) = 0.15-0.20 mm from traces
- Via stitching every 3-5 mm

---

## Design Rules Summary

### Minimum Specifications (JLCPCB)

| Parameter | Min Value | Recommended |
| --- | --- | --- |
| Trace width | 0.09 mm | 0.15 mm |
| Trace spacing | 0.09 mm | 0.15 mm |
| Via drill | 0.2 mm | 0.3 mm |
| Via pad | 0.45 mm | 0.6 mm |
| Annular ring  | 0.13 mm | 0.15 mm |

### Impedance-Controlled Traces

| Type | W | S (pair) | Sg (to GND) | Layer | Notes |
| --- | --- | --- | --- | ----- | --- |
| 50Ω SE (RF) | 0.36 mm | — | 0.20 mm | L1 | CPWG Microstrip |
| 100Ω Diff (LVDS) | 0.20 mm | 0.15 mm  | 0.20 mm | L6 | Edge-coupled CPWG  |
| 50Ω SE (Digital) | 0.36 mm | — | 0.20 mm | L6 | CPWG Microstrip |
| **50Ω SE (L3)** | **0.22 mm** | — | N/A | **L3** | **Stripline** |
| **100Ω Diff (L3)**  | **0.15 mm** | **0.12 mm** | N/A | **L3** | **Coupled Stripline** |

---

## Net Classes (KiCad)

```
Net Class: RF_50OHM (L1)
  Track Width: 0.36 mm
  Clearance: 0.20 mm         ← Sg (gap to GND pour)
  Nets: RF_IN, DSA1_*, DSA2_*, RF_FILTR_*, RF_1, F2912_*

Net Class: LVDS_100OHM (L6)
  Track Width: 0.20 mm
  Clearance: 0.20 mm         ← Sg (gap to GND pour)
  Diff Pair Gap: 0.15 mm     ← S (gap between pair)
  Nets: DA*_P, DA*_N, DB*_P, DB*_N, CLKOUTA, CLKOUTB, CLK_0, CLK_B

Net Class: DIGITAL_50OHM (L6)
  Track Width: 0.36 mm
  Clearance: 0.20 mm         ← Sg (gap to GND pour)
  Nets: TX_D*, DSA_*, FLT_V*, RX_TX_MODE

Net Class: L3_50OHM (L3 Stripline)
  Track Width: 0.22 mm       ← Narrower than L1/L6!
  Clearance: 0.15 mm         ← If using pour
  Nets: Control signals routed on L3

Net Class: L3_DIFF_100OHM (L3 Coupled Stripline)
  Track Width: 0.15 mm
  Diff Pair Gap: 0.12 mm     ← S (gap between pair)
  Clearance: 0.15 mm         ← If using pour
  Nets: ADC_OF_P, ADC_OF_N

Net Class: POWER
  Track Width: 0.5 mm (min), 1.0 mm (preferred)
  Clearance: 0.25 mm
  Nets: +5V, +3.3V*, +1.8V*, GND
```

---

## Routing Guidelines

### L1 (Analog/RF) — Microstrip

1. Keep RF traces short and direct
2. Maintain GND pour on both sides of traces (Sg = 0.20 mm)
3. Use GND vias (via stitching) every 2-3 mm along RF paths
4. Avoid 90° corners (use 45° or arcs)
5. **W = 0.36 mm** for 50Ω

### L3 (Signal) — Stripline

1. **Use narrower traces:** W = 0.22 mm for 50Ω (NOT 0.36 mm!)
2. **Differential pairs:** W = 0.15 mm, S = 0.12 mm for 100Ω
3. L3 is between L2 (GND) and L4 (+5V = AC ground)
4. Pour is optional — impedance controlled by two reference planes
5. If using GND pour: Sg = 0.15 mm, via stitch to L2
6. Keep high-speed signals away from vias to L4 (+5V)
7. ADC_OF differential pair: maintain length matching ±0.5 mm

### L4 (+5V Power Plane)

1. Keep as solid as possible (acts as AC ground for L3)
2. Add bypass capacitors (100nF + 10µF) near IC power pins
3. Connect bypass cap GND to L2 and L5 via short vias
4. Minimize cuts/splits in +5V plane under L3 signal traces

### L6 (Digital/LVDS) — Microstrip

1. Route LVDS pairs with matched lengths (±0.5 mm within pair)
2. Match all ADC data pairs to clock pair (±5 mm)
3. Keep LVDS pairs at least 3× spacing from other signals
4. Use GND vias between differential pairs
5. **W = 0.20 mm, S = 0.15 mm** for 100Ω differential
6. **W = 0.36 mm** for 50Ω single-ended

### Via Stitching

- Spacing: 2-3 mm around RF traces (L1)
- Spacing: 3-5 mm for L3 (if using pour)
- Via size: 0.3 mm drill / 0.6 mm pad
- Connect L2 and L5 GND planes with vias at board edges
- Vias from L3 GND pour → L2 (NOT to L4!)

---

## Length Matching Requirements

| Signal Group | Layer | Matching Tolerance  |
| --- | ----- | --- |
| LVDS data pairs (DA/DB) | L6 | ±0.5 mm within pair |
| All LVDS to CLKOUT | L6 | ±5 mm |
| CLK_0/CLK_B pair | L6 | ±0.5 mm |
| TX_D0-TX_D15 | L6 | ±3 mm |
| **ADC_OF_P/ADC_OF_N** | **L3** | **±0.5 mm within pair** |

---

## Verification Checklist

### L1/L6 (Microstrip)
- [ ] L2 and L5 are solid GND planes (no splits under RF/LVDS)
- [ ] All RF traces on L1 have GND pour with Sg = 0.20 mm
- [ ] LVDS pairs on L6 are length-matched (±0.5 mm)
- [ ] Via stitching around RF sections on L1

### L3 (Stripline)
- [ ] L3 traces use W = 0.22 mm (NOT 0.36 mm like L1/L6!)
- [ ] ADC_OF differential pair: W = 0.15 mm, S = 0.12 mm
- [ ] ADC_OF pair is length-matched (±0.5 mm)
- [ ] No cuts in L2 (GND) or L4 (+5V) under L3 signal traces

### L4 (+5V Power)
- [ ] L4 is mostly solid (AC ground for L3)
- [ ] Bypass caps (100nF + 10µF) placed near each IC
- [ ] Bypass cap GND connected to L2/L5 with short vias

### General
- [ ] GND planes (L2, L5) connected with vias at board edges
- [ ] L3 GND pour (if used) connected to L2, NOT L4

---

## References

- [JLCPCB Impedance Calculator](https://jlcpcb.com/impedance)
- [JLCPCB 6-Layer PCB](https://jlcpcb.com/6-layer-pcb)
- [JLCPCB Stackup Guidelines](https://jlcpcb.com/blog/six-layer-pcb-stackup-and-buildup-guidelines)
- [GitHub JLCPCB Stackups](https://github.com/gsuberland/jlcpcb_autogenerated_stackups)

---

**Document Version:** 1.3
**Date:** 2026-02-07

### Changelog

**v1.3 (2026-02-07):**

- **NEW:** Added L3 Stripline section with calculations
- L3 50Ω Single-Ended: W = 0.22 mm (KiCad Calculator verified)
- L3 100Ω Differential: W = 0.15 mm, S = 0.12 mm
- Updated Layer Assignment table with Line Type column
- Added L3_50OHM and L3_DIFF_100OHM net classes
- Added L3 and L4 routing guidelines
- Updated Impedance-Controlled Traces table with L3 parameters
- Updated Verification Checklist for L3/L4

**v1.2 (2026-02-07):**

- **CRITICAL FIX:** Corrected inner copper thickness to 0.0152 mm per JLCPCB specs
- Updated core thickness to ~0.42 mm for 1.6 mm total board thickness
- Added note about JLCPCB actual vs theoretical copper values
- Added source reference to JLCPCB Impedance Calculator

**v1.1 (2026-02-06):**

- Updated 50Ω SE trace: W = 0.36 mm, Sg = 0.20 mm (KiCad Calculator verified)
- Updated 100Ω Diff pair: W = 0.20 mm, S = 0.15 mm, Sg = 0.20 mm
- Added cross-section diagrams for CPWG structures
- Clarified terminology: S (pair gap) vs Sg (gap to GND pour)

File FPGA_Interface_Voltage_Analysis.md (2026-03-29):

# FPGA Interface Voltage Level Analysis

## Project: SDR LTC2209 on ALINX AXU2CGB

**Date**: 2026-01-24
**Version**: 1.0

---

## 1. ALINX AXU2CGB Expansion Connectors

### 1.1 Summary Table

| Connector | FPGA Banks | I/O Voltage | Bank Type | Notes |
|---|---|---|---|---|
| **J12** | BANK65, BANK66 | **1.2V** | HP (High Performance) | MIPI shares BANK65 at 1.2V |
| **J15** | BANK25, BANK26 | **3.3V** | HR (High Range) | Confirmed in User Manual |

### 1.2 Source Documentation

From ALINX AXU2CGAB User Manual (Part 13: 40-Pin Expansion Header):

> "The IO port of the **J15** expansion port is connected to the ZYNQ chip **BANK25 and BANK26**, and the **level standard is 3.3V**."

From Part 14 (MIPI Camera Interface):

> "The differential signal of MIPI is connected to the HP IO of **BANK64 and 65**, and the **level standard is +1.2V**"

Since BANK65 is shared between MIPI and J12, and MIPI operates at 1.2V, **J12 I/O voltage is 1.2V**.

### 1.3 Schematic References

| Schematic Page | Content |
|---|---|
| Page 4 | BANK25, BANK26 - VCCO connected to VCCIO (3.3V from LDO) |
| Page 5 | BANK64 - VCCO_HP = 1.2V |
| Page 6 | BANK65, BANK66 - VCCO_HP = 1.2V |
| Page 23 | J12, J15 connector pinouts |
| Page 24 | PMIC - power rail generation |

---

## 2. Project Control Signal Mapping

### 2.1 J701 → J12 Connection (1.2V FPGA I/O)

From netlist analysis, the following control signals connect through **J701** to **J12**:

| Signal | J701 Pin | Function | Destination IC | Required Logic Level |
|---|---|---|---|---|
| DSA_SCLK | 27 | SPI Clock | PE43711 | 1.8V - 5V |
| DSA_DATA | 26 | SPI Data | PE43711 | 1.8V - 5V |
| DSA_LE1 | 24 | Latch Enable | PE43711 | 1.8V - 5V |
| DSA_LE2 | 25 | Latch Enable | PE43711 | 1.8V - 5V |
| I2C_SCL | 34 | I2C Clock | LTC2209 | 1.8V - 3.3V |
| I2C_SDA | 33 | I2C Data | LTC2209 | 1.8V - 3.3V |
| FLT_V1 | 28 | Filter Select | Relay/Switch | TBD |
| FLT_V2 | 29 | Filter Select | Relay/Switch | TBD |
| FLT_V3 | 30 | Filter Select | Relay/Switch | TBD |
| FLT_V4 | 31 | Filter Select | Relay/Switch | TBD |
| RX_TX_MODE | 32 | TX/RX Control | PE4257 | 1.8V - 5V |

### 2.2 J901 → J15 Connection (3.3V FPGA I/O)

J901 connects to J15 which operates at **3.3V**. Currently used primarily for:
- ADC data bus (D0-D15)
- Clock signals
- OF (Overflow) indicator

---

## 3. Voltage Compatibility Analysis

### 3.1 PROBLEM: 1.2V FPGA Output → 1.8V/3.3V Logic Devices

**FPGA J12 output characteristics (1.2V VCCO):**
- VOH (Output High): ~1.1V typical
- VOL (Output Low): ~0.1V typical

**PE43711 (DSA) input requirements (VDD = 1.8V):**
- VIH (Input High, min): 0.65 × VDD = **1.17V**
- VIL (Input Low, max): 0.35 × VDD = **0.63V**

**Analysis:**
- FPGA VOH (1.1V) is **marginally below** PE43711 VIH (1.17V)
- This creates unreliable logic HIGH detection!

**LTC2209 I2C requirements:**
- Operates at 1.8V or 3.3V logic
- At 1.8V: VIH ≈ 1.17V
- FPGA 1.2V output is marginal

### 3.2 Voltage Margin Calculation

```
PE43711 at VDD = 1.8V:
  VIH (min) = 0.65 × 1.8V = 1.17V
  FPGA VOH = ~1.1V (at 1.2V VCCO)
  Margin = 1.1V - 1.17V = -0.07V  ← NEGATIVE MARGIN!

PE43711 at VDD = 3.3V:
  VIH (min) = 0.65 × 3.3V = 2.145V
  FPGA VOH = ~1.1V
  Margin = 1.1V - 2.145V = -1.045V  ← SEVERE MISMATCH!
```

### 3.3 Risk Assessment

| Scenario | Risk Level | Description |
|---|---|---|
| 1.2V FPGA → 1.8V logic | **HIGH** | Marginal VIH, temperature-dependent failures |
| 1.2V FPGA → 3.3V logic | **CRITICAL** | Will not work - needs level shifter |
| 3.3V FPGA → 3.3V logic | **LOW** | Compatible (J15 → J901) |

---

## 4. Serial Resistor Impact Analysis

### 4.1 Voltage Drop Calculation

For a series resistor with FPGA output:

**Formula:** V_drop = I_drive × R_series

**Typical scenarios:**

| R_series | I_drive | V_drop | V_output (from 1.2V) |
|---|---|---|---|
| 22Ω | 4mA | 0.088V | 1.112V |
| 33Ω | 4mA | 0.132V | 1.068V |
| 47Ω | 4mA | 0.188V | 1.012V |
| 22Ω | 8mA | 0.176V | 1.024V |
| 33Ω | 8mA | 0.264V | 0.936V |

**For 3.3V FPGA output (J15):**

| R_series | I_drive | V_drop | V_output |
|---|---|---|---|
| 22Ω | 8mA | 0.176V | 3.124V |
| 33Ω | 8mA | 0.264V | 3.036V |
| 47Ω | 8mA | 0.376V | 2.924V |

### 4.2 Impact Assessment

**For 1.2V J12 outputs:**
- Series resistors will **worsen** the already marginal VIH situation
- 33Ω at 4mA reduces output to 1.068V (below VIH threshold)
- **NOT RECOMMENDED** without level shifting

**For 3.3V J15 outputs:**
- Series resistors are acceptable
- 33Ω at 8mA gives 3.036V - still well above 3.3V VIH threshold (~2.0V)
- **RECOMMENDED** for ESD protection and signal integrity

---

## 5. Solutions

### 5.1 Option A: Move Control Signals to J15 (3.3V) - RECOMMENDED

**Advantages:**
- Native 3.3V compatibility with PE43711, LTC2209
- No level shifters needed
- Simple PCB modification

**Implementation:**
- Reconnect DSA_*, I2C_*, FLT_*, RX_TX_MODE from J701 to J901
- Use J901 pins currently marked as UNCONNECTED

**J901 Available Pins:**
- Pins 21-36 appear to be unconnected in current design
- Sufficient for all control signals

### 5.2 Option B: Add Level Shifters on Project Board

**For 1.2V → 1.8V conversion:**
- Use bidirectional level shifter (e.g., TXS0108E, SN74LVC8T245)
- I2C requires open-drain compatible level shifter (e.g., PCA9306)

**Circuit example:**
```
FPGA (1.2V) → Level Shifter → PE43711 (1.8V)
     |              |
   VCCO_A=1.2V   VCCO_B=1.8V
```

**Recommended ICs:**

| IC | Type | Channels | Speed | Application |
|----|---|---|---|---|
| TXS0108E | Auto-direction | 8 | 100Mbps | SPI, GPIO |
| SN74LVC8T245 | Unidirectional | 8 | 420Mbps | High-speed SPI |
| PCA9306 | I2C bidirectional | 2 | 400kHz | I2C bus |

### 5.3 Option C: Verify Actual BANK66 Voltage

BANK66 might be at 1.8V (VCCAUX) instead of 1.2V.

**Verification method:**
1. Measure VCCO_66 voltage on ALINX board
2. Check pins B7, D3, E6 (VCCO_66) on FPGA

If BANK66 = 1.8V:
- Some J12 pins would be 1.8V compatible
- Need to identify which pins are in BANK66 vs BANK65

---

## 6. Serial Resistor Recommendations

### 6.1 For J15 Signals (3.3V) - Project Board

| Signal Type | R_series | Justification |
|---|---|---|
| SPI CLK | 22-33Ω | Edge rate control, reflection reduction |
| SPI Data | 22-33Ω | Signal integrity |
| Latch Enable | 33-47Ω | Slow signal, ESD protection |
| I2C | 0Ω (none) | Open-drain with external pull-ups |
| GPIO | 33-47Ω | ESD protection |

### 6.2 For J12 Signals (1.2V) - NOT RECOMMENDED

If level shifters are used:
- Place series resistors **after** level shifter (on 1.8V/3.3V side)
- Do NOT add resistors on 1.2V FPGA side (worsens margin)

---

## 7. Recommended Design Changes

### 7.1 Immediate Actions

1. **Verify BANK66 voltage** by measurement
2. **Evaluate moving control signals** from J701→J901 (Option A)
3. If J701 must be used, **add level shifters**

### 7.2 PCB Modifications

**If moving to J901 (J15, 3.3V):**

| Signal | New J901 Pin | Old J701 Pin |
|---|---|---|
| DSA_SCLK | 27 | 27 |
| DSA_DATA | 26 | 26 |
| DSA_LE1 | 24 | 24 |
| DSA_LE2 | 25 | 25 |
| I2C_SCL | 34 | 34 |
| I2C_SDA | 33 | 33 |
| FLT_V1 | 28 | 28 |
| FLT_V2 | 29 | 29 |
| FLT_V3 | 30 | 30 |
| FLT_V4 | 31 | 31 |
| RX_TX_MODE | 32 | 32 |

**Add series resistors on J901 lines:**

```
J901.27 (DSA_SCLK) ──[22Ω]── PE43711
J901.26 (DSA_DATA) ──[22Ω]── PE43711
J901.24 (DSA_LE1) ──[33Ω]── PE43711
J901.25 (DSA_LE2) ──[33Ω]── PE43711
J901.34 (I2C_SCL) ──────── LTC2209 (no series R, has pull-up)
J901.33 (I2C_SDA) ──────── LTC2209 (no series R, has pull-up)
J901.28-31 (FLT_Vx) ──[33Ω]── Filter control
J901.32 (RX_TX_MODE) ──[33Ω]── PE4257
```

---

## 8. Summary

### Critical Findings

1. **J12 (connected to J701) operates at 1.2V** - insufficient for 1.8V/3.3V logic devices
2. **J15 (connected to J901) operates at 3.3V** - compatible with all project ICs
3. **Serial resistors on 1.2V outputs will worsen voltage margins**
4. **Recommended solution: Move control signals to J901 (3.3V)**

### Risk Matrix

| Current Design | Risk | Mitigation |
|---|---|---|
| DSA control via J701 (1.2V) | HIGH | Move to J901 or add level shifter |
| I2C via J701 (1.2V) | HIGH | Move to J901 or add PCA9306 |
| ADC data via J901 (3.3V) | LOW | Add series resistors for protection |

---

## Revision History

| Version | Date | Changes |
|---|---|---|
| 1.0 | 2026-01-24 | Initial analysis |

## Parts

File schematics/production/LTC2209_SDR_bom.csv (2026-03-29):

Designator | Footprint | Quantity | Value | LCSC Part #
_68, _67, _66, _65, _64, _63, _62, _61, _60, _59, _58, _57, _56, _55, _54, _53, _52, _51, _50, _49, _48, _47, _46, _45, _44, _43, _42, _41, _40, _39, _38, _37, _36, _35, _34, _33, _32, _31, _30, _29, _28, _27, _26, _25, _24, _23, _22, _21, _20, _19, _18, _17, _16, _15, _14, _13, _12, _11, _10, _9, _8, _7, _6, _5, _4, _3, _2, , 1, 2, 3 |  | 71
C101, C601, C602, C613, C614, C702, C703, C704, C705, C913 | 0508 | 10 | 1uF
C102, C103, C403, C404, C501, C502, C607, C608, C621, C708, C712, C801, C904, C912 | 0603 | 14 | 1µF
C201, C207, C208 | 0603 | 3 | 22uF
C202, C203, C205, C617, C802, C803, C804, C805, C806, C807, C808, C809, C818, C819, C820, C821, C901, C902, C903, C905, C906, C907, C908, C919 | 0603 | 24 | 100nF
C204, C605, C606 | 0603 | 3 | 1uF
C206 | 0603 | 1 | 10uF
C301 | 0603 | 1 | 2.2nF
C302, C348 | 0603 | 2 | 270pF
C303 | 0603 | 1 | 1.2nF
C304 | 0603 | 1 | 68pF
C305 | 0603 | 1 | 91pF
C306, C324 | 0603 | 2 | 1.5nF
C307, C315 | 0603 | 2 | 1nF
C308 | 0603 | 1 | 2.7nF
C309, C316, C330, C334 | 0603 | 4 | 150pF
C310 | 0603 | 1 | 680pF
C311, C352, C364, C367 | 0603 | 4 | 51pF
C312 | 0603 | 1 | 3.3nF
C313 | 0603 | 1 | 430pF
C314 | 0603 | 1 | 300pF
C317 | 0603 | 1 | 36pF
C318 | 0603 | 1 | 560pF
C319, C322 | 0603 | 2 | 330pF
C320 | 0603 | 1 | 820pF
C321, C355 | 0603 | 2 | 39pF
C323, C357 | 0603 | 2 | 12pF
C325, C342 | 0603 | 2 | 130pF
C326 | 0603 | 1 | 8,2pF
C327 | 0603 | 1 | 470pF
C328, C360, C363, C369 | 0603 | 4 | 24pF
C329, C344 | 0603 | 2 | 220pF
C331, C336 | 0603 | 2 | 390pF
C332 | 0603 | 1 | 10pF
C333, C335, C371 | 0603 | 3 | 18pF
C337, C338 | 0603 | 2 | 56pF
C339, C368 | 0603 | 2 | 3.3pF
C340 | 0603 | 1 | 120pF
C341 | 0603 | 1 | 6,8pF
C343, C347, C351 | 0603 | 3 | 82pF
C345 | 0603 | 1 | 16pF
C346 | 0603 | 1 | 3.9pF
C349 | 0603 | 1 | 23pF
C350, C373 | 0603 | 2 | 30pF
C353 | 0603 | 1 | 33pF
C354 | 0603 | 1 | 100pF
C356 | 0603 | 1 | 110pF
C358 | 0603 | 1 | 27pF
C359 | 0603 | 1 | 1pF
C361 | 0603 | 1 | 15pF
C362 | 0603 | 1 | 47pF
C365 | 0603 | 1 | 7.5pF
C366 | 0603 | 1 | 13pF
C370, C374 | 0603 | 2 | 2pF
C372 | 0603 | 1 | 0,75pF
C603, C620, C701, C707, C709, C711, C909, C911 | 0603 | 8 | 10µF
C604, C706, C710, C910 | 0603 | 4 | 4.7µF
C609, C610 | 0805 | 2 | 100nF
C611, C612, C916, C917 | 0805 | 4 | 1µF
C615, C616 | 0805 | 2 | 10nF
C618 | 0603 | 1 | 8.2pF
C619, C625 | 0603 | 2 | 20pF
C622, C623 | 0603 | 2 | 1000pF
C626 | 0603 | 1 | 2.2µF
FB102, FB201, FB402, FB501, FB601, FB701, FB702, FB901 | 0603 | 8 | 1000Ω@100MHz
IC101, IC405, IC501 | SOT-23-5 | 3 | LP5907MFX-3.3
IC104, IC502 | QFN50P400X400X90-25N-D | 2 | PE43711A-Z
IC201, IC202 | QFN50P400X400X90-25N-D | 2 | PE42582A-X
IC203 | WSON-12-1EP_3x2mm_P0.5mm_EP1x2.65_ThermalVias | 1 | LM27762
IC401, IC402, IC403 | QFN50P400X400X80-21N-D | 3 | F2912NCGI8
IC601 | QFN50P400X400X80-25N-D | 1 | LTC6432AIUF-15#PBF
IC602, IC702, IC703, IC902 | SON50P300X300X80-11N-D | 4 | TPS7A9401DSCR
IC701 | QFN50P900X900X80-65N | 1 | LTC2209IUPPBF
IC801 | QFN50P900X900X90-65N-D | 1 | SI5391B-A-GM
IC901 | QFN50P700X700X100-49N | 1 | MAX5885EGM+D
J101 | SMA_BAT_Wireless_BWSMA-KWE-Z001 | 1 | SMA RX
J701, J901 | PinHeader_2x20_P2.54mm_Vertical | 2 | Adafruit Pin Header 2x20 Female 2.54mm
J902 | SMA_BAT_Wireless_BWSMA-KWE-Z001 | 1 | SMA TX
L301, L305 | 1008 | 2 | 4.7u
L302 | 1210 | 1 | 6.8u
L303 | 1008 | 1 | 3.3u
L304, L321, L340 | 1008 | 3 | 1.2u
L306 | 1008 | 1 | 2.7u
L307, L311, L326 | 1008 | 3 | 3.9u
L308, L313, L324, L325 | 1008 | 4 | 1.5u
L309, L315, L347 | 1008 | 3 | 1u
L310 | 1008 | 1 | 6.2u
L312 | 1008 | 1 | 15u
L314, L317, L318 | 1008 | 3 | 2.2u
L316 | 1008 | 1 | 620n
L319 | 1008 | 1 | 4.7
L320 | 1008 | 1 | 910n
L322, L346 | 1008 | 2 | 560n
L323, L327, L338 | 1008 | 3 | 390n
L328, L331, L339 | 1008 | 3 | 680n
L329 | 1008 | 1 | 270nF
L330 | 0603 | 1 | 200n
L332 | 1008 | 1 | 750n
L333 | 1008 | 1 | 1.8u
L334 | 1008 | 1 | 330n
L335, L342 | 1008 | 2 | 470n
L336, L337 | 0603 | 2 | 180n
L341 | 1008 | 1 | 270n
L343 | 0603 | 1 | 160n
L344 | 1008 | 1 | 150n
L345 | 0603 | 1 | 300n
L348 | 0603 | 1 | 110nH
L349 | 0603 | 1 | 24nH
L350 | 0603 | 1 | 130nH
L351 | 0603 | 1 | 160nH
L352 | 0603 | 1 | 75nH
L353 | 0805 | 1 | 240nH
L354, L355, L605, L606, L609, L610 | 0603 | 6 | 100nH
L356 | 0603 | 1 | 68nH
L601, L604 | L_Changjiang_FNR8065S | 2 | 470µH
L602, L603 | L_Sunlord_SWPA252010S | 2 | 560nH
L607, L608 | 0603 | 2 | 27nH
L611, L612 | L_Sunlord_SWPA4030S | 2 | 47µH
R101, R902 | 0603 | 2 | 1MΩ
R102, R201, R202, R501, R614, R615, R618, R702, R703, R706, R707, R708, R710, R711, R905, R906, R908 | 0603 | 17 | 10kΩ
R203 | 0603 | 1 | 160kΩ
R204, R205 | 0603 | 2 | 91kΩ
R206 | 0603 | 1 | 130kΩ
R601, R602 | 0603 | 2 | 360Ω
R603, R606 | 0603 | 2 | 390Ω
R604, R605 | 0603 | 2 | 54Ω
R607, R608, R612, R613 | 0603 | 4 | 10Ω
R609, R610 | 0603 | 2 | 33Ω
R611, R701, R919 | 0603 | 3 | 100Ω
R616 | 0603 | 1 | 30kΩ 1%
R617, R705, R909 | 0603 | 3 | 47kΩ
R619 | 0603 | 1 | 3.6kΩ 1%
R620, R621 | 0603 | 2 | 82Ω
R622, R623 | 0603 | 2 | 2.2kΩ
R704, R907 | 0603 | 2 | 22kΩ 1%
R709 | 0603 | 1 | 12kΩ 1%
R801, R802 | 0603 | 2 | 4.7kΩ
R901 | 0603 | 1 | 2kΩ
R903, R904 | 0603 | 2 | 25Ω
R910, R911, R912, R913, R914, R915, R916, R917, R918, R920, R921 | 0603 | 11 | 47Ω
T101, T602, T901, T902 | CX2041NLT | 4 | CX2041NLT 1:1
T601 | TTWB20101LB | 1 | TTWB-2-A 1:2
TVS101, TVS901 | D_SOD-323_HandSoldering | 2 | CDSOD323-T05LC
U902 | Texas_Instruments-DCK0005A-0-0-IPC_C | 1 | SN74LV1T04DCKR
X801 | Oscillator_SMD_Kyocera_2520-6Pin_2.5x2.0mm | 1 | 38.4 MHz TCXO

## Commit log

2026-03-29 Initial release: LTC2209 SDR Transceiver
    Open-source 16-bit direct-sampling HF SDR transceiver covering
    9 kHz - 72 MHz. Hardware design (schematics + PCB) complete.
    Licensed under CERN-OHL-S v2.
    [All_Bloks_of_project.kicad_sch, LTC2209_SDR_bom.csv]
2026-03-29 Translate PROJECT_OVERVIEW_v2.0.md from Ukrainian to English
    Translate all Ukrainian text to English throughout the technical
    overview document for international accessibility. No technical
    content changed — only language.
